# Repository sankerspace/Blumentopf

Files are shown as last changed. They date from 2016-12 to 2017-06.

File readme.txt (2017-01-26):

Hier ist ein Spannungsmess-Testprogramm (VoltageCheck) sowie der ganze restliche 
Code (noch in Entwicklung) vom Messknoten (SensorNode) und einem 
Beispiel-Controller (RF_Receiver).
###### Einrichtung Arduino IDE #########
Im Ordner libraries sind sämtliche Bibliotheken die wir dür das Projekt 
benötigen In der Arduino IDE muss der Standard Ordner für die installierten 
Libraries geändert werden auf die Location von der Blumentopf Repository, damit 
sind automatisch sämtlichen notwendigen Libraries für unser Projekt aufgenommen.

###### Sensor Node ######

X	Sensoren auslesen (Implementiert und getestet. Geht sehr gut)
X	Protokoll
		implementiert und getestet:
			Beim Startup beim Controller registrieren 
			ID beziehen, falls noch keine vorhanden
			Daten übertragen
			Schlafdauer empfangen und schlafen gehen
			Speichern der Daten im EEPROM bei RF Ausfall und auslesen der Daten, 
			wenn vom Server angefordert
X	RTC synchronisieren
-	Interrupt Alarm von RTC

** Known problems: **

	If RTC is unplugged, sketch will hang due to a bug in the I2C library.

###### Controller  ######

Ist ein simpler Controller, der zeigt wie man die Funktionen von dem Protokoll 
verwendet.
Features:
	ID-verwaltung:
		-) Hat der Node noch keine ID wird eine vom Controller vergeben.
		-) Der Controller führt eine Liste mit den ihm bekannten Nodes.
	Kommunikationsprotokoll:
		-) Der Controller antwortet auf Registrations und Messdaten-Nachrichten.
		   Dabei schickt er Instruktionen mit.

Fehlt:
	Die Möglichkeit über ein Front-End die Messintervalle eizustellen und 
	Messknoten mit Pumpknoten zu verknüpfen.	Ein Algorithmus wann welche Pumpen 
	aktiviert werden und ggf. ein Frontend für die Parameter des Algorithmus

###### Raspberry Pi  ######

    fehlt noch!!!

	Data Logging:
		-) Alle Nachrichten werden passiv geloggt.
		   Den Teil kann man dann auf dem Pie übernehmen und ein Datenbankinterface 
		   basteln

###### PumpNode ######

Hardware fertig

Software:
    Pumpe ansteuerbar
    RF Kommunikation

fehlt noch:
    Interrupt/Sleep vom Pump-Node
    Protokoll Implementierung

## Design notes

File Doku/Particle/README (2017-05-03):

Controller should work on a Particle Photon, but also can run an Arduino
Here you can find a description how to prepare/compile to run the Controller.ino
on a Particle Photon

Configuration on the breadboard:
-Particle Photon
-DS3231 Real Time Controller
-nRF24L01+ 

Pin Configuration:
  rf-Gnd/Pin1 to ground-breadboard
  rf-Vcc/Pin2 to  3,3v-breadboard
  rf-CE/Pin3 to   D6-photon
  rf-CS/Pin4 to   A2-photon
  rf-SCK/Pin5 to  A3-photon
  rf-MOSI/Pin6 to A5-photon
  rf-MISO/Pin7 to A4-photon

  DS3231/VCC  to   3,3v-breadboard
  DS3231/Gnd  to   Ground-breadboard
  DS3231/SCL  to   D0-photon  
  DS3231/SDA  to   D1-photon

1)  Prepare Atom IDE (half online/ half offline)

  https://atom.io/packages/particle-dev
 
2) Create Symbolic Links to all cpp and h files necessary for controller.ino
    
    Start bash script <path-to_repo>/Doku/Particle/createSymbols.sh
    which automatically creates alls symbol links to these files 
    inside folder  <path-to_repo>/Controller 
 
3)  Include R24 Lib and use firmware version 0.6.0 particle dev 

  Our Library Rf24 in folder libraries has no compability for Spark processors,
  in order we have to introduce the "particle-rf24" library from 
  particle public libraries  
  -> include in project-properties : dependencies.particle-rf24=0.0.2
      in a new line
      
  some compile errors occured in photon firmware version 0.6.1,
  so i cannot choose the most actual firmware version and have to
  compile for version 0.6.0
   
4) Use particle-cli (for use on command line and with better error output)

    sudo npm install -g particle-cli
   
  but you have to install nodejs before!

  Tips Atom IDE:
  
    packets you should install: 
    (https://benmccormick.org/2016/01/11/the-most-interesting-atom-packages-ive-found-so-far/)
    git-time-machine
    language-particle
    todo-show  
    git-plus
    autocomplete
    autocomplete-clang
    autocomplete-paths
    minimap

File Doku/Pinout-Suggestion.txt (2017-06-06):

Das Pinout ist ein Kompromiss zwischen dem was der Ezio auf seinen Platinen hat und dem was
wir in dem Programm verwenden. Außerdem können dann die DS_1302 und DS_3231/3232 RTCs leicht
ausgetauscht werden.
RF24 := CE, CS, MOSI, MISO, SCK, IRQ
 Arduino_Pin/Particle_Pin
 12/A4 13/A3   9/D6 
----------------------------
|MISO | SCK  |  CE  | GND |
----------------------------
|IRQ  |MOSI  |  CS  | VCC |
----------------------------
       11/A5  10/A2   
    RF CHIP           |
   ___________________|
     __    __    __   |                   
    |  |  |  |  |  |  |
    |  |  |  |  |  |  |
    |  |  |  |  |  |  |
____|  |__|  |__|  |__|

RTC  := SDA, SCL
/*
**** pinout                                                                                                
***                0    |    1    |    2    |    3    |    4    |    5    |    6    |    7    |    8    |   9     |   10   |   11   |   12   |   13   |
=====================================================================================================================================================
* Controller  | --------| --------|         |         |  Button |         |         |         |  if ARDUINO same sas pump,sensornode, otherwise PARTICLE
* SensorNode  | --------| --------|         |         |         |  DHT11  |SENS_PWR |         |         |   CE    |   CS   |  MOSI  |  MISO  |   SCK  |   
* PumpNode    | --------| --------| Pump1   |  Pump2  |  Button |         |         |         |         |   CE    |   CS   |  MOSI  |  MISO  |   SCK  |   
* Particle	  |   SDA   |   SCL   |         |         | RTC_PWR |         |   CE    |         |------------------------------------------------------

*             |    A0   |    A1   |    A2   |    A3   |    A4   |    A5   |    A6   |    A7   | 
=====================================================================================================================
* Controller  |         |         |         |         |         |         |  -----  |  -----  |
* SensorNode  | Battery |  Light  |Moisture1|Moisture2|   SDA   |   SCL   |  -----  |  -----  |
* PumpNode    |         |         |         |         |   SDA   |   SCL   |  -----  |  -----  |
* Particle	  |         |         |   CS    |   SCK   |  MISO   |  MOSI   |  -----  
*/

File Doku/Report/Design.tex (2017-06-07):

For the topology of the network multiple options have been considered. Eventually we decided to split up the sensing and pumping functionality into separate nodes, the sensor node and the pump node.
There can be up to $%2^{16}$ nodes of both types to offer flexibility with the size of the system. A controller node coordinates the communication of the nodes and the front-end.
The front-end should offer access to the main functions of the system. In particular it has to display the sensor values and offer the possibility to activate individual pumps.
Additionally a dater logger was requested to record all communication  and store it into a database.\\
To reset the nodes a button has been implemented to reset the devices. It has to be pressed during restart. Instead of a button it also is sufficient to pull the digital pin 4 high some seconds during restart.

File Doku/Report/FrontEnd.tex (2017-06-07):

In order to adjust, maintain and control the system, it is necessary to have direct access to certain features. As it is not feasible to interact with the Photon or an Arduino a front-end has been developed. Note that the functions offered by the front-end are also accessible through console.particle.io or the Particle app. However the front-end is more user friendly. The front end offers the possibility to mate a sensor node with a pump node, to see the sensor data of a particular node and to manually start the watering of a flower pot.
This chapter can be considered as a user guide for operating the whole system.
In the following the features are introduced with an example each.

\subsubsection{Mapping}
For watering the flowers the system needs to know which sensors monitor which flowers. This is called the mapping and can be done via the front end.
Each pump node can support up to two pumps and every sensor node can own up to two moisture sensors. \textbf{A word of warning}: It is important to make sure to chose the right pump and the right sensor, otherwise the flower might not be watered, but the floor instead.\\
A pump does not need to be mapped and a moisture sensor does not need to be mapped to.
To map a pump node to a sensor node they have to be selected in the drop down list. Further the user has to chose which moisture sensor should be and which pump should be mapped. An example is shown in the following figure.

\begin{figure}[h!]
	\begin{center}
	
	\caption{How to map a pump to a moisture sensor.}
	\label{fig:mapping}
	\end{center}
\end{figure}

\subsubsection{Sensor View}
To monitor the most recent environment values, all sensor data can be listed in the front end.

\begin{figure}[h!]
	\begin{center}
	
	\caption{Overview of the sensor data.}
	\label{fig:sensor_overview}
	\end{center}
\end{figure}

\subsubsection{Manual Watering}
Under special circumstances one might decide to manually add some water to a flower. In this case the front end offers a comfortable way to do so.
The user only has to chose the flower from the drop down menu and how long the water should be running. (in seconds)
The following figure shows an example.

\begin{figure}[h!]
	\begin{center}
	
	\caption{How to manually water a flower.}
	\label{fig:manual_watering}
	\end{center}
\end{figure}

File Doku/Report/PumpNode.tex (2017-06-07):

The purpose of the pump node is to serve as an actuator and activate a pump for a specified time on request of the controller. An early draft involved a 3d printed reservoir where the electronics would be incorporated. However it turned out to be inflexible and therefore only the pump mountings have been printed and the mountings are attached to a bucket. From that bucket a hose leads to the pump and further to the flower.
It was required that the pump node supports two pumps which can be activated individually. Since the ATmega itself cannot provide sufficient current to power the pumps, a relay is used for each pump. % which relay shield do we use here?
A specific protocol takes care of the reliable communication between the pump node and the controller. It has been carefully designed to avoid freezing of the node and to ensure reliable operation of the pumps.\\

\subsubsection{Actuator}
As the task of the pump node is to water flowers, it is equipped with two pumps. Alternatively solenoid valves have been considered, however pumps are easier to use and a reliable solution. The chosen peristaltic pumps require high currents around 200mA and a voltage of 12V. Therefore they cannot be powered by Arduino pins, but have to be powered from an own power source like a voltage booster or an additional power supply. We chose an external 12V power supply to power the node.
The Arduino switches two relays which in turn power the pumps. As high current is needed, the pumps are not activated concurrently, but sequentially. They typically will be active for around 30 seconds.
Figure \ref{fig:pumpnode} illustrates a pumpnode with one pump.

\begin{figure}[H]
	\begin{center}
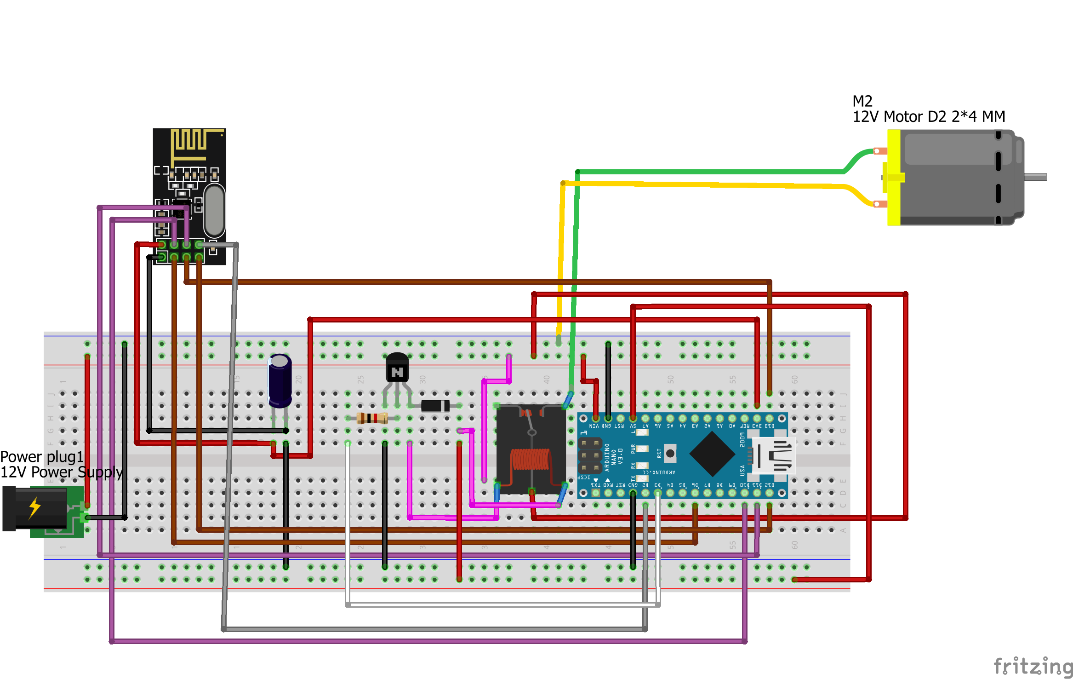
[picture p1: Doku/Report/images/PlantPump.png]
	
	\caption{Breadboard schematic of the pump node.}
	\label{fig:pumpnode}
	\end{center}
\end{figure}

\subsubsection{Fall-back Mode}
To guarantee a dependable solution resistant to external factors such as a failing internet connection or wireless jamming attacks, a fall-back mode has been implemented to water the flowers reliably, even if the control node is unavailable.

For this purpose the pump node uses all incoming messages, also those addressed to other nodes, to detect the availability of the controller. If the pump node does not receive any messages from the controller for a specified timeout\_duration, it assumes the controller is offline and goes into a fall-back mode.

The parameters for the fall-back mode are:
\begin{itemize}
\item timeout\_duration
\item enable
\item time
\item watering\_duration
\end{itemize}

These parameters can be set at the IOT front-end-interface and get transmitted to the pump nodes by the controller at the pump node registration and with every pump request. (so in case they get changed the pump node stays up to date)
In case the fall-back is disabled, no action takes place if the controller is unavailable.
In case the fall-back is enabled and the controller is unavailable, daily at the specified time the pump node pumps for the specified watering\_duration.

This mechanism does not guarantee a perfect watering, however it prevents the plants from drying.

To make the fall-back visible to the monitor node, a notification message is broadcasted via the wireless network containing the timestamp, pump duration and last timestamp from a controller message.

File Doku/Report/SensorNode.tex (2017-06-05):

%about the sensor node...

The sensor node provides data about the current state of the flower environment to the controller.
It has been developed as a low power device which guarantees long battery duration.
Arduino has been chosen as platform for this node because of its powerful libraries and support. Also the microcontroller has to offer sufficient ADCs and GPIO pins to access all required modules such as communication chip, real time clock and sensors. Other platforms such as XBee could not be used, as they do not directly support protocols such as TWI. Also they are expensive.
In particular we chose the Arduino Mini 3.3V 8MHz board, as it is the most basic board and therefore offering the lowest power consumption. Further details about minimizing the power consumption are explained in \ref{sec:lowpower}.

The sensors used are:
\begin{itemize}

\item \textbf{DHT11 - Temperature and humidity sensor}\\
The datasheet claims this sensor reaches a repeatability of $\pm0.2°C$ for the temperature and an accuracy of $\pm 5\%$ for humidity. It seems to be a widely used sensor for arduino projects, however in operation its humidity accuracy was far worse than promised by the manufacturer and a cumbersome calibration of the sensor is needed. Further research showed that it is not always a reliable humidity sensor and probably should be replaced by the more expensive DHT22 or other alternatives. We kept the sensor in the setup, however no decision has been based on its data.

\item \textbf{Moisture sensor}\\
We tried two types of moisture sensors. A resistance based sensor and a capacitive sensor. The electrodes used for the resistance sensors interact with the water in the soil as current flows. This pollutes the soil and destroys the sensor over time. Performing only sporadic measurements postpones this effect, however it cannot be avoided. Capacitive sensors do not interact with the soil as they measure the humidity through the capacity of the soil, not its resistance. So no current flows through the soil and there are no metallic or corrosive electrodes.\\

The resistance based sensor consists of two parts, the resistance probe (YL-69) and a control board (YL-38). The probe will be put into the measured soil, while the board should stay dry. It provides an analog signal. The ATmega328 has a 10 bit ADC, so the result read from the ADC is an integer between 0 and 1023.\\

The test showed that in a dry state the sensor shows 1023. Connecting the electrodes with a finger leads to a value around 1000.\\
Also in dry soil the readout is 1023, but as we pour water into the pot, it continuously decreases down to a few hundred.\\

We might have to calibrate the moisture levels for different flower or soil types, but in general the sensor seems to do the job very well.\\

The capacitive sensor used is the SEN0193. It is handled the same way as the YL-69 sensor on the software side, however it does not influence the soil.

\item \textbf{Brightness sensor}\\
To gather information about the brightness in the environment, a photoresistor has been used. This is a semiconductor that reacts to light. The manual of the sensor suggested the range of the photoresistor is between 500$\Omega$ (bright) and 50$k\Omega$ (dark). 
Further it suggested to use a 1$k\Omega$ resistor for the voltage divider. An arduino tutorial \citep{misc:photoresistor_tutorial} suggested 10 $k\Omega$. So we decided to measure the actual resistor values and use the formula from the lecture to calculate the matching resistor of the voltage divider. % , 26$k\Omega$ was a good choice  

The measurements showed that the actual photoresistor range is 500$\Omega$ to 1.7$M\Omega$.\\
\begin{equation}
R_1 = \sqrt{R_{max}*R_{max}} = \sqrt{500*1700000} = \sqrt{850000000} = 29k\Omega
\end{equation}

The closest resistor available to us was 26$k\Omega$.\\
These values differ to those suggested by the tutorials, but since also the photoresistor has different values, our choice seems feasible. Also we are convinced a higher resistor will not harm the components and result in lower power consumption in contrast to a small resistor.\\
So we connected the chosen pulldown resistor between ground and an ADC pin of the Arduino. To complete the voltage divider the photoresistor was connected between VCC and the ADC pin.\\

The sensor worked very well in the tests and showed a value between 30 (covered sensor) and 950 (next to a light bulb). That confirmed our choice of the resistor.\\

\item \textbf{Battery Voltage Sensor}\\
As the sensor node is powered by a battery it is good to have information about the battery status.
This can be done by measuring the voltage of the battery via a voltage divider. There are two ways of setting the voltage reference of the ADC unit. Either the VCC of the ATmega or the internal reference voltage of 1.1V can be used.
The former has the advantage of higher accuracy, assuming a stable supply voltage. However a supply voltage lower than 3.3V cannot be measured correctly. Notice that the ATmega328 will continue to operate even at a supply voltage as low as 2.7V, although some external components might fail.
 The second version has the advantage that also supply voltages below 3.3V can be measured, however it has to be calibrated for each ATmega individually to be as precise.

In any case a voltage divider is needed to convert the voltage from 0-6V to 0-3.3V respectively 0-1.1V. The design of the voltage divider is a trade\-off between measurement precision and power consumption. \cite{misc:battery_voltage_measurement} If its total resistance is low, the power consumption of the voltage divider is too high for a low power device. If the resistance is too high, the measurement will become unstable and a capacitor becomes necessary to smooth the measurements. We decided to use a resistance of $100k\Omega$ between GND and the ADC pin as well as $500k\Omega$ between VCC and the ADC pin. This seemed to be a good trade-off without requiring a capacitor.

% Ezio: 
% VCC - 1MO - ADC - 39kO - (1MO / 470kO) - 22kO - GND (1MO / 381kO)

% Ours:
% VCC - 500kO - ADC - 108kO - GND 			(500kO / 100kO)

\end{itemize}

\subsubsection{Low Power Capability}
\label{sec:lowpower}

As mentioned before, the Arduino Mini 3.3V 8MHz is the basis of our sensor node platform. However the Arduino uses about 6 mA in standby. With this current consumption a set of batteries (assuming a capacity of 2000mAh) would be empty within 14 days. In a network consisting of 7 sensor nodes, every second day batteries would be needed to be changed. This motivates to look into further power saving techniques for the Arduino.\\

\subsubsection{Power supply}

One of the obvious questions is the supply of the operating voltage. It has been looked into the following options:

\begin{itemize}
\item \textbf{Using the Arduino voltage regulator}
The Arduino board can be powered directly from the battery and generate its own supply voltage.
However this regulator is very inefficient.

\item \textbf{Using an external voltage regulator}
A more efficient external regulator can be used instead of the onboard regulator. The original regulator will still consume a small current, even if not used. Therefore it should be removed in this case. The external regulator will require a supply voltage of typically 100-200mV above the output voltage. The regulator tested by us, MCP1700-3302E, needs 3.5V, so in case of three batteries this is 1.17V per battery.\\
During the discharge process of a battery its output voltage drops. Once the voltage drops under the required supply voltage of a voltage regulator, the output voltage of the regulator will not match 3.3V anymore.\\
Figure \ref{fig:dischage_curve} illustrates the battery voltage of a AA NiMH battery over different loads. %It is important to notice that with a low load the battery voltage stays above 1.17V for a longer period.
It is important to notice that with a low load the ampere hours obtained from the battery increases. So decreasing the current used by the system by half results in more than just doubled battery life.
In our application the load is less than 1mA with some 15mA pulses during data transmission. This is even far less than the uppermost line indicates. It can be concluded that the energy remaining in the battery once its voltage drops below 1.17V is less than 400mA.

\item \textbf{Using a buck-boost converter}
A conventional voltage regulator needs a supply voltage of at least little over 3.3V to provide a 3.3V output.
A buck-boost converter like the Pololu reg 12a which we tested, can convert voltages above 0.5V to constant 3.3V.\\
This is beneficial because of the dropping battery voltage during the discharge process. 
A buck-boost converter has a lower required supply voltage (0.5V) and therefore gets nearly all energy out of the battery. However it turned out that for very low currents, like in our sensor node, the power consumed by the Pololu is much higher than for the linear voltage regulator. This diminishes the advantage of the Pololu and even turns it into the worse choice in terms of energy efficiency. Regarding costs the linear power regulator beats the pololu by an order of magnitude.

\end{itemize}

\begin{figure}[htbp]
\begin{center}
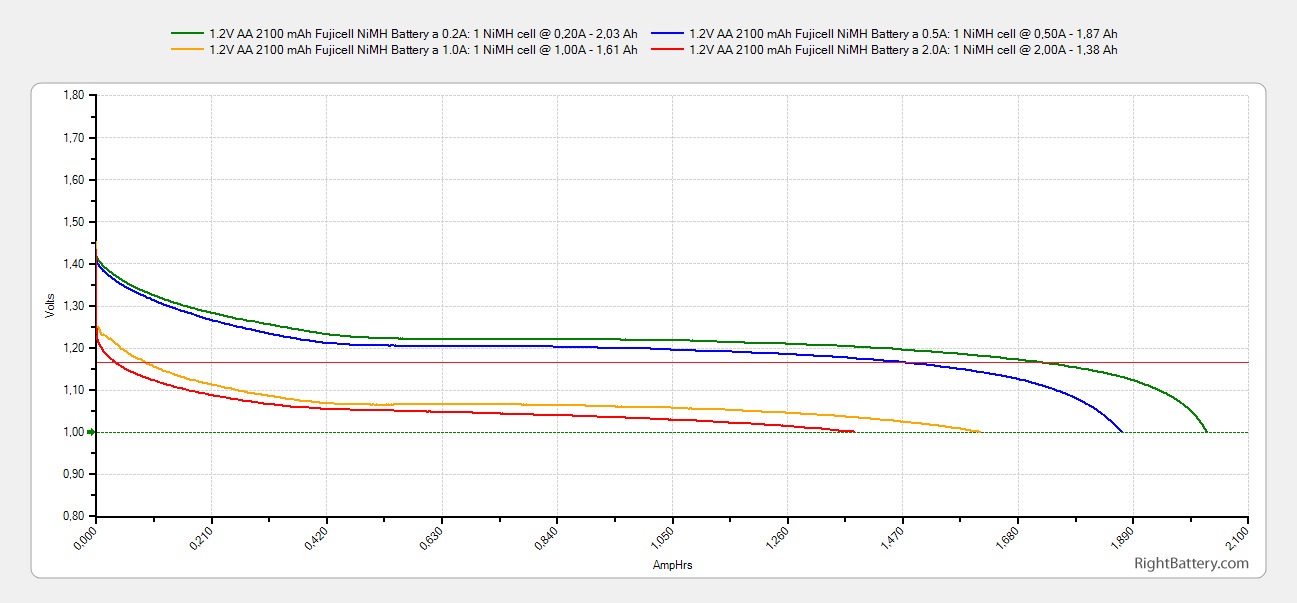
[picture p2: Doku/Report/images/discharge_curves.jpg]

\end{center}
\caption{Discharge curves over different currents}
\label{fig:dischage_curve}
\end{figure}

We tried all solutions in our tests, however for the final solution we recommend the linear voltage regulator with adequate batteries (3 x 1.5V or 4 x 1.2V).

\subsubsection{Power consumption optimizations}
To make the batteries last as long as possible, the node should use as little power as possible.\\
The biggest power safer is to put the microcontroller and all peripheral devices including all sensors into sleep mode as much as possible.\\
This reduces the power of the system to around 1.5mA and gives 8 weeks of battery life per node. This is a big improvement, however far away from a convenient solution and the technical limits.\\
One further optimization is to remove the power LED used to indicate the Arduino is running, as there is no need for it and the LED uses a lot of power. The LED can be removed by adding tin to connect both legs, heating them up uniformly and pulling away the LED with tweezers. This decreases the consumption to about 0.26 mA (45 weeks). \\
Disabling TWI before sleep saved another 170µA.\\
Removing the parasiting onboard voltage regulator saved further 75µA. However de-soldering of medium sized SMD components requires special equipment, skills or patience.\\
The resulting consumption for the design including all final components and using the external voltage regulator is 15µA. (4.5V ==> 67.5µW)
Using the Pololu the same design needs 90µA (4.5V ==> 405µW).
It can be concluded that in this situation an appropriate voltage regulator is more efficient than a Pololu. Also the voltage divider is a far cheaper solution.\\

\paragraph{Battery}
One crucial factor obviously is the kind of battery itself. The following summarizes the key issues of batteries in our application.
\begin{itemize}
\item \textbf{Voltage}\\
It must be mentioned that every battery type operates at a different voltage, what has to be considered at the choice of battery.
Three 1.5V alkaline batteries have been assumed in the calculations above, resulting in 4.5V total. Using rechargeable batteries with 1.2V each, like nickel metal hydride batteries, the resulting total 3.6V are just slightly above the threshold for the voltage regulator to operate, so they will fail very soon. In this case the Pololu would have the better performance. For operation with the voltage regulator 3x1.5V LSD NiMH batteries or 4x1.2V rechargeable alkaline batteries are recommended.

\item \textbf{Capacity}\\
Obviously batteries with higher capacity last longer without replacing them.

\item \textbf{Temperature range}\\
Not all batteries withstand extreme temperatures. For example conventional NiMH batteries are not supposed to be used in cold environments, while their self-discharge rate drastically increases at high temperatures. LSD NiMH however can resist cold temperatures.

\item \textbf{Self discharge rate}\\
Conventional NiMH batteries have a high self discharge rate. Even if not used, they loose half their energy after one month. Low self discharge NiMH (LSD NiMH) batteries loose only a fraction of this energy per month $(<3\%)$ and can be used for several years without recharging.
\end{itemize}

\subsubsection{PCB}
In order to incorporate all components into a small box, a PCB has been designed by our supervisor using the Fritzing tool. The yellow traces are on the top side and the orange traces on the bottom. To offer flexibility with the power supply of the sensors, it can be selected whether they should be powered by the normal VCC pin or powered by an arduino pin to be able to deactivate all sensors during low power phases.
The board has been produced by the Fritzing company tested with our software. It works as expected.
\begin{figure}[h!]
	\begin{center}
%	\includegraphics[scale=2]{images/PlantSensorPCB.pdf}
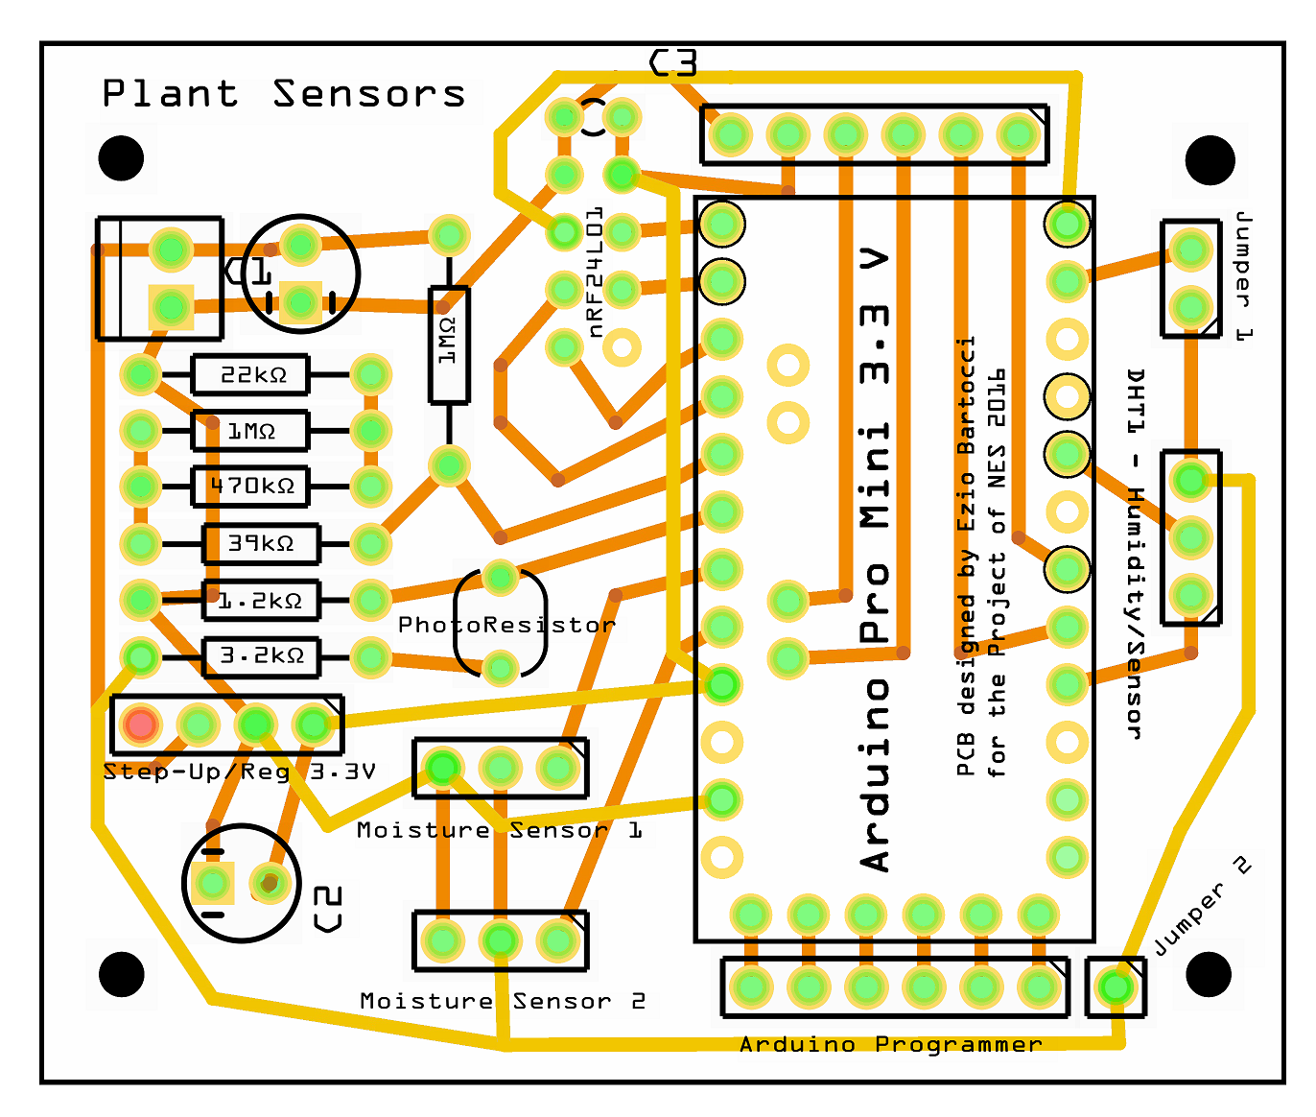
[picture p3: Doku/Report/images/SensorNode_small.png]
	
	
	\caption{PCB design of the sensor node.}
	\label{Setup_overview}
	\end{center}
\end{figure}

\subsubsection{Data storage}
As the communication between a sensor node and the controller might be faulty, the data shouldn't get lost. If the sensor node sends data to the controller and doesn't get a response, the data is stored in the EEPROM of the sensor node until the controller requests the data.
The size of the EEPROM is limited to 1KB, therefore only around 25 data sets fit into the storage.
Another issue with using EEPROM as storage is that the write cycles it endures are limited. Therefore an algorithm has been developed to ensure equal wearout of the EEPROM cells. In case the controller does not request the data and the EEPROM memory is full, the oldest data in the storage is replaced with the most recent data. 

\subsubsection{State diagram}

\begin{figure}[H]
	\begin{center}
	
	\caption{State diagram of the sensor node.}
	\label{Setup_overview}
	\end{center}
\end{figure}

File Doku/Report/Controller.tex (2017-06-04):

The controller keeps track of all nodes and handles their registration. It coordinates the communication of the sensor and pump nodes and maintains a schedule of which node is allowed to transmit at which time.
The controller also executes the watering policy that the user has selected for each flower.
For this task it wirelessly communicates with the sensor nodes situated in the flower pots and the pump nodes situated next to the water tanks. The sensor nodes provide the controller with the most recent measurement values, whereas the pump nodes executes the pump commands received from the controller.
The controller also provides an interface for the front end to get the newest data and to perform certain actions.
It was a restriction to use the Particle Photon as controller hardware.

\subsubsection{State diagram}

\begin{figure}[h!]
	\begin{center}
	
	\caption{State diagram of the controller.}
	\label{Setup_overview}
	\end{center}
\end{figure}

States:
\begin{itemize}
	\item Check pending tasks

		This is the begin of the loop() Function. The controller will always come back to this state to check which tasks are pending. The following actions are possible:

		\begin{itemize}
			\item A NRF24 message is arrived, process this message.
			\item Also if an interactive command has arrived via the IOT framework, this command has to be processed. (Typically sending an instruction to a Motor Node)
			\item If, according to the watering schedule, a pump node should take an action now, the controller goes to the ``Send Watering Command to Motor Node'' state
			\item If a Motor Node did not respond as expected, an error handling sequence should be started (writing to log and if needed respond to the IOT framework)
		\end{itemize}

	\item Send Watering Command to Motor Node
		Whenever the controller decides a pump node should start to pump, this function is called. 			It prepares and sends a message to concerned the pump node. It also writes the message content to a log file.
	\item Write Pump Node Timeout to Log
		If a pump node does not reply within the specified timeout duration, an entry into the log file has to be written. In case the command of the concerned message has been triggered by the IOT framework, the controller will move to the ``Send Error Notification to App'' state. Otherwise it enters the ``Reschedule Watering'' state.
	\item Send Error Notification to App
			If a IOT command could not be successfully executed, the IOT framework has to be notified about the problem. Afterwards the controller goes back to checking for pending tasks.
	\item Reschedule Watering
		If a scheduled watering task failed, the controller needs to reschedule this watering task.
		There are many possible algorithms for this such as:
		\begin{itemize}
			\item Skip this watering task and proceed as usual
			\item Retry the watering task a certain number of times. If it fails, proceed as usual
			\item Reschedule the watering of this pump node in a given fashion.
		\end{itemize}
		For a first version it is sufficient to skip the watering, if it failed.
		
	\item Write Motor Node Response to Log File
		If a motor node responds to a control command, this response has to be logged to a log file. Afterwards the controller processes the response.
	\item Mark Command as Read
		The watering command is marked in the controller internal command list as ``read by the node''. Otherwise a timeout would occur.
		
	\item Process State Message
		As the pump node finished to pump, it will send a state message to the controller indicating the end of the pump sequence. This message can be responded to by the controller, but it doesn't have to be.
		
	\item Process Sensor Data
		When the controller receives data from a sensor node, it stores the data. Later this data will be used for the watering algorithm and statistical analysis. Afterwards it will check whether the sensor node has data stored in its EEPROM. This will be the case if the controller was unavailable to the sensor node for some time. If there is EEPROM data the controller can choose whether it wants the data to be transmitted now, later or not at all. If the latter is the case, the node will delete its sensor data. If the controller has currently time to receive the EEPROM data, it should request it. Otherwise the data might get lost. If there is a lot of traffic scheduled in the next slots, the controller can postpone the EEPROM data transmission. In this case the next sensor node transmission should be scheduled in a slot that is followed by empty slots. This way it is guaranteed that there is enough time to transmit all EEPROM data.
	
	\item Respond
		In the respond state a response is prepared and sent to the node from which the last message has been received. Its content is based on the previous states.

\end{itemize}

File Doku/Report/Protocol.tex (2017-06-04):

The application itself and project requirements bring certain constraints regarding the system architecture and protocol. For communication XBee, WiFi and RF24L01 chips have been considered. Because of costs, power and sensor constraints XBee and WiFi turned out to be not feasible.

\paragraph{Sensor Node <--> Controller}
One main constraint is that the sensor nodes should not be connected by cables. Therefore the communication with the controller has to be wireless and the node cannot be powered by the power grid.
For receiving messages on a wireless interface, the wireless module has to be actively listening continuously. The chosen modules RF24L01+ use about 15mA in listening mode. That makes a controller initiated communication impossible, as the constantly activated listening mode of the RF module would drain the batteries within 5 days.
To solve this problem, we chose that the sensor node initiates the transmission, waits for the answer of the controller and puts the RF module to a low power mode. This is an elegant solution for keeping the power down, however it is much more difficult to implement. It makes it necessary that every sensor is assigned a precise time at which it is expected to send its next measurement data to the controller in advance. Therefore the controller has the task of coordinating these timeslots and synchronizing the clocks of the sensor nodes. New sensor nodes should automatically be integrated into this schedule.

For registering nodes and perform data exchanges a protocol has been developed. The developed library provides access to the protocol registers to use the functionality of the protocol.

Status register in the node --> controller message:

\begin{table}[htbp]
        \small
        \setlength\tabcolsep{2pt}
\begin{tabular}{ |l|c|c|c|c|c|c|r| }
%  Test ID & measurement base frequency [MHz] & measurement scale factor & PLL factors (m/d) & measurement frequency [MHz] & PISO base frequency [MHz] & PISO scale factor & PISO frequency [MHz]\\ \hline
\hline
  Bit & name & description & 0 - meaning & 1 - meaning\\ \hline
  0 & RTC\_RUNNING\_BIT & RTC is paired on the node & no RTC & RTC paired \\ \hline
  1 & MSG\_TYPE\_BIT & type of message & registration request & data \\ \hline
  2 & NEW\_NODE\_BIT & new or known node & known node & new node \\ \hline
  3 & EEPROM\_DATA\_AVAILABLE & is data in the EEPROM & no data & data available\\ \hline
  4 & EEPROM\_DATA\_PACKED & kind of data & live data & EEPROM data\\ \hline
  5 & EEPROM\_DATA\_LAST & more EEPROM data pending & more data & not more data \\ \hline
  6 & NODE\_TYPE & type of node & sensor node & pump node\\ \hline
\end{tabular}\\
\end{table}

Status register in the controller --> node message:

\begin{table}[htbp]
        \small
        \setlength\tabcolsep{2pt}
\begin{tabular}{ |l|c|c|c|c|c|c|r| }
%  Test ID & measurement base frequency [MHz] & measurement scale factor & PLL factors (m/d) & measurement frequency [MHz] & PISO base frequency [MHz] & PISO scale factor & PISO frequency [MHz]\\ \hline
\hline
  Bit & name & description & 0 - meaning & 1 - meaning\\ \hline
  0 & REGISTER\_ACK\_BIT & registration acknowledge & no reg & registration\\ \hline
  1 & FETCH\_EEPROM\_DATA1 & &  &  \\ \hline
  2 & FETCH\_EEPROM\_DATA2 &  & &  \\ \hline
  3 & ID\_INEXISTENT & id invalid & id valid & id invalid\\ \hline
  7 & ID\_REGISTRATION\_ERROR &  & &  \\ \hline
\end{tabular}\\
\end{table}

Further the combination ``00'' in the FETCH\_EEPROM\_DATA1/2 bits indicates the EEPROM data shouldn't be transmitted now, ``01'' means the sensor node should send the data now and ``10'' means the node should delete the stored EEPROM data.

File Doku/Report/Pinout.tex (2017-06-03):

To quickly change the role of an ardunino, it is a good idea to have a standardized pinout for all sketches. The following tables summarize the pinout.\\

Digital Pins:

\begin{table}[htbp]
        \small
        \setlength\tabcolsep{2pt}
\begin{tabular}{ |l|*{7}{c|}r| }
%  Test ID & measurement base frequency [MHz] & measurement scale factor & PLL factors (m/d) & measurement frequency [MHz] & PISO base frequency [MHz] & PISO scale factor & PISO frequency [MHz]\\ \hline
  \hline   & 2 & 3 & 4 & 5 & 6 & 7 & 8 & 9-13 \\ \hline
  Controller & DS\_1302 & DS\_1302 & DS\_1302 &  &  & Button  & RTC\_PWR &  RF24   \\ \hline
  SensorNode & DS\_1302 & DS\_1302 & DS\_1302 &  DHT11  &         & Button  &SENS\_PWR &  RF24  \\ \hline
%  PumpNode & DS\_1302 & DS\_1302 & DS\_1302 &  Pump1  &  Pump2  & Button  &         &  RF24   \\ \hline
  PumpNode & & & &  Pump1  &  Pump2  & Button  &         &  RF24   \\ \hline
  Particle & ?? & & & & & & &  \\ \hline
\end{tabular}\\
\end{table}

Analog Pins:

\begin{table}[htbp]
        \small
        \setlength\tabcolsep{2pt}
\begin{tabular} { |l|*{7}{c|}r| }
%  Test ID & measurement base frequency [MHz] & measurement scale factor & PLL factors (m/d) & measurement frequency [MHz] & PISO base frequency [MHz] & PISO scale factor & PISO frequency [MHz]\\ \hline
  \hline   & A0 & A1 & A2 & A3 & A4 & A5 & A6 & A7 \\ \hline
  Controller & & & & & DS\_3231 & DS\_3231 & &  \\ \hline
  SensorNode & Battery & Light & Moisture1 & Moisture2 & DS\_3231 & DS\_3231 &  &  \\ \hline
%  PumpNode &  & & & & DS\_3231 & DS\_3231 & &  \\ \hline
  PumpNode &  & & & & & & &  \\ \hline
  Particle & & & & & & & &  \\ \hline
\end{tabular}\\
\end{table}

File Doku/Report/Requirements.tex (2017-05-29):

The system should substitute the need for human interaction. Therefore it has to sense as much information relevant to the task of watering as possible and it needs the possibility of adding water to the flower pots. Furthermore it should be reliable, so it doesn't have to be supervised.

\begin{itemize}
\item \textbf{All data containing information vital for the watering task has to be tracked.}
This contains ambient temperature, ambient humidity, soil moisture and brightness.
The data has to be logged in a database.

\item \textbf{Reliable flower watering through pumps or valves.}
Based on the sensor data the system has to make decision when to water the plants and for how long.
It is critical that this part is fail safe. If there are a failures of any components of the system, the water supply has to be automatically cut off to avoid damage.

\item \textbf{Any influence to the flower or surrounding through the system has to be avoided.}
This in particular concerns the choice of sensors, pipes, pumps and water tanks to not pollute the soil, keep the noise level low, being an efficient solution and not disturbing other electronic devices nearby.

\item \textbf{The hardware solution should be visually appealing.}
Since the system should be usable in living areas, it has to be as unobtrusive as possible.
As a result the data communication should be wireless and the sensor nodes run on battery.

\item \textbf{Battery powered low power sensor nodes.}
The sensor nodes should be powered by batteries, not the power grid. However the batteries also should last long time to decrease the maintenance work, what means the power supply is not trivial and needs to be paid attention to while developing the sensor node.

\end{itemize}

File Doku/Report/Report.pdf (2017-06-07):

# Network Embedded Systems [VU] Semster Project - Protocol

### Vienna University of Technology June 7, 2017

### Helmut Bergmann, Matr.Nr. 0325535

0325535@student.tuwien.ac.at

### Bernhard Fritz, Matr.Nr. 0828317

0828317@student.tuwien.ac.at

### Marko Stanisic, Matr.Nr. 0325230

0325230@student.tuwien.ac.at

Everyday life brings many repetitive tasks. As technology increases also more complicated tasks can be automatised, relieving humans from repetitive tasks. In our project we want to develop a system that handles the watering of plants in order to decrease the number of routine tasks done in a household and also to reliably continue watering even if no person is at home for a longer period of time.

## 1 Requirements

The system should substitute the need for human interaction. Therefore it has to sense as much information relevant to the task of watering as possible and it needs the possibility of adding water to the flower pots. Furthermore it should be reliable, so it doesn’t have to be supervised.

- All data containing information vital for the watering task has to be tracked. This contains ambient temperature, ambient humidity, soil moisture and brightness. The data has to be logged in a database.
- Reliable flower watering through pumps or valves. Based on the sensor data the system has to make decision when to water the plants and for how long. It is critical that this part is fail safe. If there are a failures of any components of the system, the water supply has to be automatically cut off to avoid damage.
- Any influence to the flower or surrounding through the system has to be avoided. This in particular concerns the choice of sensors, pipes, pumps and water tanks to not pollute the soil, keep the noise level low, being an efficient solution and not disturbing other electronic devices nearby.
- The hardware solution should be visually appealing. Since the system should be usable in living areas, it has to be as unobtrusive as possible. As a result the data communication should be wireless and the sensor nodes run on battery.
- Battery powered low power sensor nodes. The sensor nodes should be powered by batteries, not the power grid. However the batteries also should last long time to decrease the maintenance work, what means the power supply is not trivial and needs to be paid attention to while developing the sensor node.

1

## 2 Design

### 2.1 Sensor Node

The sensor node provides data about the current state of the flower environment to the controller. It has been developed as a low power device which guarantees long battery duration. Arduino has been chosen as platform for this node because of its powerful libraries and support. Also the microcontroller has to offer sufficient ADCs and GPIO pins to access all required modules such as communication chip, real time clock and sensors. Other platforms such as XBee could not be used, as they do not directly support protocols such as TWI. Also they are expensive. In particular we chose the Arduino Mini 3.3V 8MHz board, as it is the most basic board and therefore offering the lowest power consumption. Further details about minimizing the power consumption are explained in 2.1.1.

The sensors used are:

- DHT11 - Temperature and humidity sensor
The datasheet claims this sensor reaches a repeatability of ±0.2C for the temperature and an accuracy of ±5% for humidity. It seems to be a widely used sensor for arduino projects, however in operation its humidity accuracy was far worse than promised by the manufacturer and a cumbersome calibration of the sensor is needed. Further research showed that it is not always a reliable humidity sensor and probably should be replaced by the more expensive DHT22 or other alternatives. We kept the sensor in the setup, however no decision has been based on its data.
- Moisture sensor
We tried two types of moisture sensors. A resistance based sensor and a capacitive sensor. The electrodes used for the resistance sensors interact with the water in the soil as current flows. This pollutes the soil and destroys the sensor over time. Performing only sporadic measurements postpones this effect, however it cannot be avoided. Capacitive sensors do not interact with the soil as they measure the humidity through the capacity of the soil, not its resistance. So no current flows through the soil and there are no metallic or corrosive electrodes.

The resistance based sensor consists of two parts, the resistance probe (YL-69) and a control board (YL-38). The probe will be put into the measured soil, while the board should stay dry. It provides an analog signal. The ATmega328 has a 10 bit ADC, so the result read from the ADC is an integer between 0 and 1023.

The test showed that in a dry state the sensor shows 1023. Connecting the electrodes with a finger leads to a value around 1000.

2

Also in dry soil the readout is 1023, but as we pour water into the pot, it continuously decreases down to a few hundred.

We might have to calibrate the moisture levels for different flower or soil types, but in general the sensor seems to do the job very well.

The capacitive sensor used is the SEN0193. It is handled the same way as the YL-69 sensor on the software side, however it does not influence the soil.

- Brightness sensor
To gather information about the brightness in the environment, a photoresistor has been used. This is a semiconductor that reacts to light. The manual of the sensor suggested the range of the photoresistor is between 500Ω (bright) and 50kΩ (dark). Further it suggested to use a 1kΩ resistor for the voltage divider. An arduino tutorial
[1] suggested 10 kΩ. So we decided to measure the actual resistor values and use the formula from the lecture to calculate the matching resistor of the voltage divider.

The measurements showed that the actual photoresistor range is 500Ω to 1.7MΩ.

R1 =

p
Rmax ∗ Rmax =

√

500 ∗ 1700000 = √
850000000 = 29kΩ (1)

The closest resistor available to us was 26kΩ.
These values differ to those suggested by the tutorials, but since also the photoresistor has different values, our choice seems feasible. Also we are convinced a higher resistor will not harm the components and result in lower power consumption in contrast to a small resistor.
So we connected the chosen pulldown resistor between ground and an ADC pin of the Arduino. To complete the voltage divider the photoresistor was connected between VCC and the ADC pin.

The sensor worked very well in the tests and showed a value between 30 (covered sensor) and 950 (next to a light bulb). That confirmed our choice of the resistor.

- Battery Voltage Sensor
As the sensor node is powered by a battery it is good to have information about the battery status. This can be done by measuring the voltage of the battery via a voltage divider. There are two ways of setting the voltage reference of the ADC unit. Either the VCC of the ATmega or the internal reference voltage of 1.1V can be used. The former has the advantage of higher accuracy, assuming a stable supply voltage. However a supply voltage lower than 3.3V cannot be measured correctly. Notice that the ATmega328 will continue to operate even at a supply voltage as low as 2.7V, although some external components might fail. The second version has the advantage that also supply voltages below 3.3V can be measured, however it has to be calibrated for each ATmega individually to be as precise.

3

In any case a voltage divider is needed to convert the voltage from 0-6V to 0-3.3V respectively 0-1.1V. The design of the voltage divider is a tradeoff between measurement precision and power consumption. [2] If its total resistance is low, the power consumption of the voltage divider is too high for a low power device. If the resistance is too high, the measurement will become unstable and a capacitor becomes necessary to smooth the measurements. We decided to use a resistance of 100kΩ between GND and the ADC pin as well as 500kΩ between VCC and the ADC pin. This seemed to be a good trade-off without requiring a capacitor.

### 2.1.1 Low Power Capability

As mentioned before, the Arduino Mini 3.3V 8MHz is the basis of our sensor node platform. However the Arduino uses about 6 mA in standby. With this current consumption a set of batteries (assuming a capacity of 2000mAh) would be empty within 14 days. In a network consisting of 7 sensor nodes, every second day batteries would be needed to be changed. This motivates to look into further power saving techniques for the Arduino.

### 2.1.2 Power supply

One of the obvious questions is the supply of the operating voltage. It has been looked into the following options:

- Using the Arduino voltage regulator The Arduino board can be powered directly from the battery and generate its own supply voltage. However this regulator is very inefficient.
- Using an external voltage regulator A more efficient external regulator can be used instead of the onboard regulator. The original regulator will still consume a small current, even if not used. Therefore it should be removed in this case. The external regulator will require a supply voltage of typically 100-200mV above the output voltage. The regulator tested by us, MCP1700-3302E, needs 3.5V, so in case of three batteries this is 1.17V per battery.
During the discharge process of a battery its output voltage drops. Once the voltage drops under the required supply voltage of a voltage regulator, the output voltage of the regulator will not match 3.3V anymore.
Figure 1 illustrates the battery voltage of a AA NiMH battery over different loads. It is important to notice that with a low load the ampere hours obtained from the battery increases. So decreasing the current used by the system by half results in more than just doubled battery life. In our application the load is less than 1mA with some 15mA pulses during data transmission. This is even far less than the uppermost

4

line indicates. It can be concluded that the energy remaining in the battery once its voltage drops below 1.17V is less than 400mA.

- Using a buck-boost converter A conventional voltage regulator needs a supply voltage of at least little over 3.3V to provide a 3.3V output. A buck-boost converter like the Pololu reg 12a which we tested, can convert voltages above 0.5V to constant 3.3V.
This is beneficial because of the dropping battery voltage during the discharge process. A buck-boost converter has a lower required supply voltage (0.5V) and therefore gets nearly all energy out of the battery. However it turned out that for very low currents, like in our sensor node, the power consumed by the Pololu is much higher than for the linear voltage regulator. This diminishes the advantage of the Pololu and even turns it into the worse choice in terms of energy efficiency. Regarding costs the linear power regulator beats the pololu by an order of magnitude.

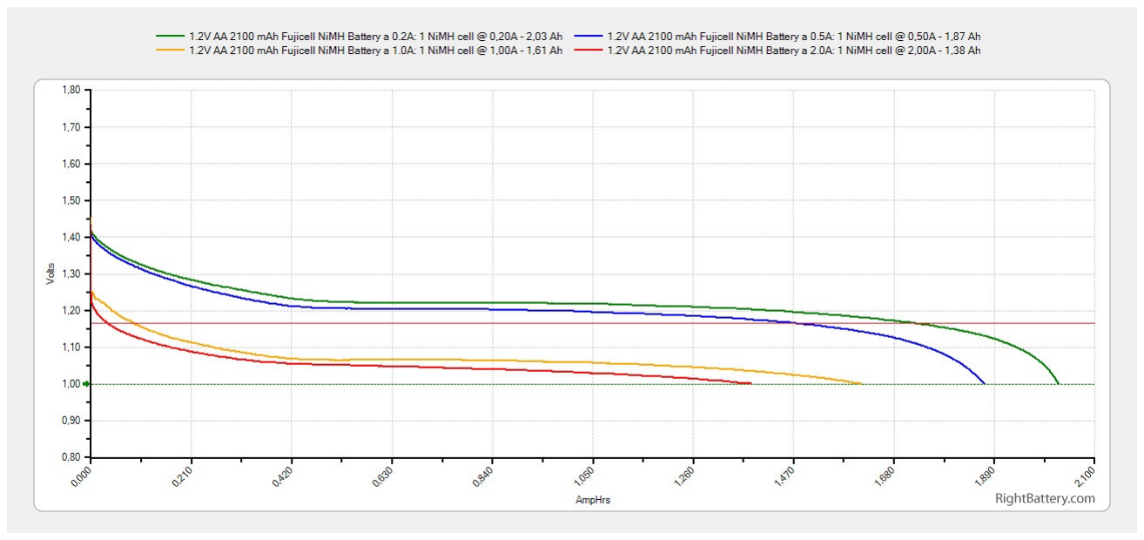
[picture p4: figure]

Figure 1: Discharge curves over different currents

We tried all solutions in our tests, however for the final solution we recommend the linear voltage regulator with adequate batteries (3 x 1.5V or 4 x 1.2V).

### 2.1.3 Power consumption optimizations

To make the batteries last as long as possible, the node should use as little power as possible.
The biggest power safer is to put the microcontroller and all peripheral devices including all sensors into sleep mode as much as possible.
This reduces the power of the system to around 1.5mA and gives 8 weeks of battery life

5

per node. This is a big improvement, however far away from a convenient solution and the technical limits.
One further optimization is to remove the power LED used to indicate the Arduino is running, as there is no need for it and the LED uses a lot of power. The LED can be removed by adding tin to connect both legs, heating them up uniformly and pulling away the LED with tweezers. This decreases the consumption to about 0.26 mA (45 weeks). Disabling TWI before sleep saved another 170µA.
Removing the parasiting onboard voltage regulator saved further 75µA. However de-soldering of medium sized SMD components requires special equipment, skills or patience.
The resulting consumption for the design including all final components and using the external voltage regulator is 15µA. (4.5V ==> 67.5µW) Using the Pololu the same design needs 90µA (4.5V ==> 405µW). It can be concluded that in this situation an appropriate voltage regulator is more efficient than a Pololu. Also the voltage divider is a far cheaper solution.

Battery One crucial factor obviously is the kind of battery itself. The following summarizes the key issues of batteries in our application.

- Voltage
It must be mentioned that every battery type operates at a different voltage, what has to be considered at the choice of battery. Three 1.5V alkaline batteries have been assumed in the calculations above, resulting in 4.5V total. Using rechargeable batteries with 1.2V each, like nickel metal hydride batteries, the resulting total 3.6V are just slightly above the threshold for the voltage regulator to operate, so they will fail very soon. In this case the Pololu would have the better performance. For operation with the voltage regulator 3x1.5V LSD NiMH batteries or 4x1.2V rechargeable alkaline batteries are recommended.
- Capacity
Obviously batteries with higher capacity last longer without replacing them.
- Temperature range
Not all batteries withstand extreme temperatures. For example conventional NiMH batteries are not supposed to be used in cold environments, while their self-discharge rate drastically increases at high temperatures. LSD NiMH however can resist cold temperatures.
- Self discharge rate
Conventional NiMH batteries have a high self discharge rate. Even if not used, they loose half their energy after one month. Low self discharge NiMH (LSD NiMH) batteries loose only a fraction of this energy per month (< 3%) and can be used for several years without recharging.

6

### 2.1.4 PCB

In order to incorporate all components into a small box, a PCB has been designed by our supervisor using the Fritzing tool. The yellow traces are on the top side and the orange traces on the bottom. To offer flexibility with the power supply of the sensors, it can be selected whether they should be powered by the normal VCC pin or powered by an arduino pin to be able to deactivate all sensors during low power phases. The board has been produced by the Fritzing company tested with our software. It works as expected.

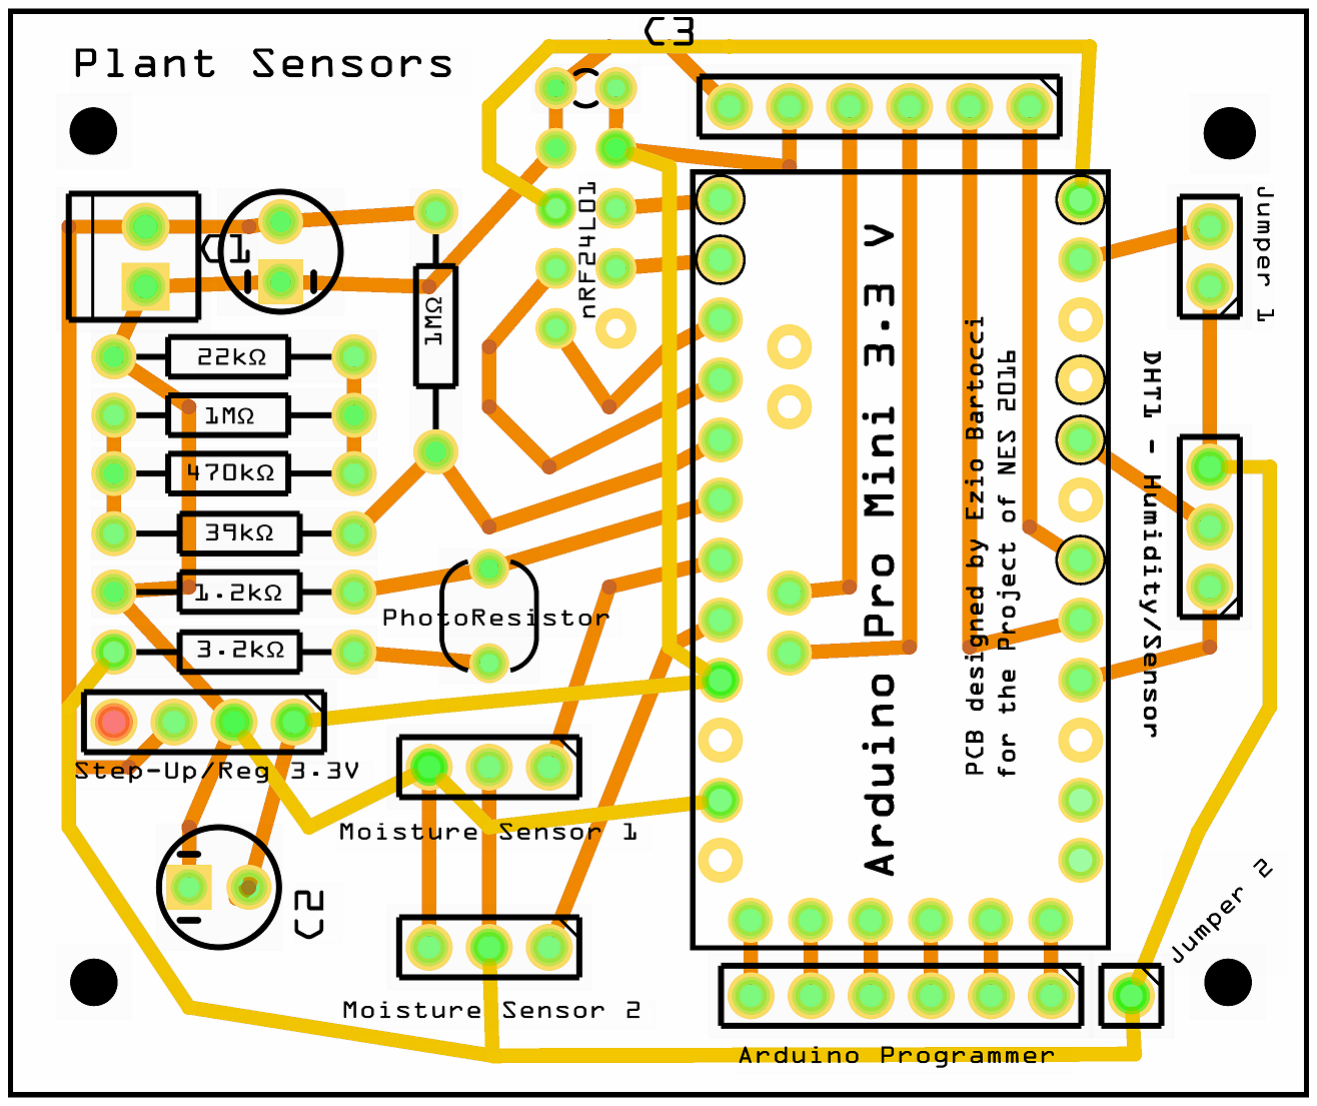
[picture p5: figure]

Figure 2: PCB design of the sensor node.

### 2.1.5 Data storage

As the communication between a sensor node and the controller might be faulty, the data shouldn’t get lost. If the sensor node sends data to the controller and doesn’t get a response, the data is stored in the EEPROM of the sensor node until the controller requests the data. The size of the EEPROM is limited to 1KB, therefore only around 25 data sets fit into the storage. Another issue with using EEPROM as storage is that the write cycles it endures are limited. Therefore an algorithm has been developed to ensure equal wearout of the EEPROM cells. In case the controller does not request the data and the EEPROM memory is full, the oldest data in the storage is replaced with the most recent data.

7

8

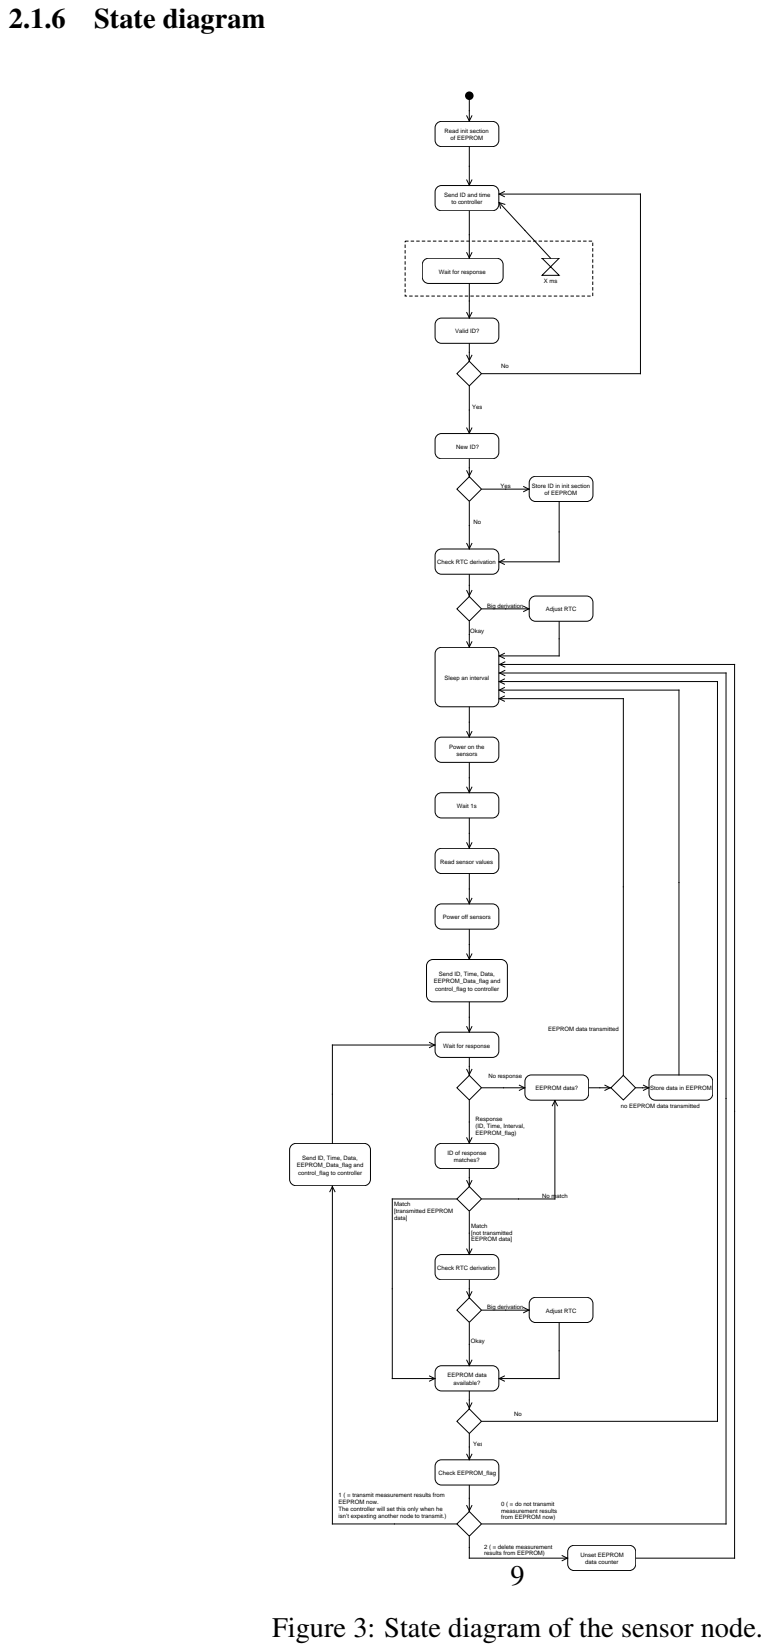
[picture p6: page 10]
2.1.6 State diagram; EEPROM data?; Valid ID?; Unset EEPROM data counter; Check EEPROM_flag; EEPROM data available?; Adjust RTC; Wait 1s; New ID?; No response; Yes; Match [transmitted EEPROM data]; Okay; Big derivation; Match [not transmitted EEPROM data]; No match; Response (ID, Time, Interval, EEPROM_flag)

Read init section
of EEPROM

Send ID and time
to controller

Wait for response

Store ID in init section

Check RTC derivation

Sleep an interval

Power on the
sensors

Read sensor values

Power off sensors

Send ID, Time, Data,
EEPROM_Data_flag and
control_flag to controller

EEPROM data transmitted

Store data in EEPROM

no EEPROM data transmitted

ID of response
matches?

1 ( = transmit measurement results from
EEPROM now.
The controller will set this only when he
isn't expexting another node to transmit.)

0 ( = do not transmit
measurement results
from EEPROM now)

2 ( = delete measurement
results from EEPROM)

Figure 3: State diagram of the sensor node.

### 2.2 Controller

The controller keeps track of all nodes and handles their registration. It coordinates the communication of the sensor and pump nodes and maintains a schedule of which node is allowed to transmit at which time. The controller also executes the watering policy that the user has selected for each flower. For this task it wirelessly communicates with the sensor nodes situated in the flower pots and the pump nodes situated next to the water tanks. The sensor nodes provide the controller with the most recent measurement values, whereas the pump nodes executes the pump commands received from the controller. The controller also provides an interface for the front end to get the newest data and to perform certain actions. It was a restriction to use the Particle Photon as controller hardware.

### 2.2.1 State diagram

States:

- Check pending tasks

This is the begin of the loop() Function. The controller will always come back to this state to check which tasks are pending. The following actions are possible:

– A NRF24 message is arrived, process this message.

– Also if an interactive command has arrived via the IOT framework, this command has to be processed. (Typically sending an instruction to a Motor Node)

– If, according to the watering schedule, a pump node should take an action now, the controller goes to the “Send Watering Command to Motor Node” state

– If a Motor Node did not respond as expected, an error handling sequence should be started (writing to log and if needed respond to the IOT framework)

- Send Watering Command to Motor Node Whenever the controller decides a pump node should start to pump, this function is called. It prepares and sends a message to concerned the pump node. It also writes the message content to a log file.
- Write Pump Node Timeout to Log If a pump node does not reply within the specified timeout duration, an entry into the log file has to be written. In case the command of the concerned message has been triggered by the IOT framework, the controller will move to the “Send Error Notification to App” state. Otherwise it enters the “Reschedule Watering” state.
- Send Error Notification to App If a IOT command could not be successfully executed, the IOT framework has to be notified about the problem. Afterwards the controller goes back to checking for pending tasks.

10

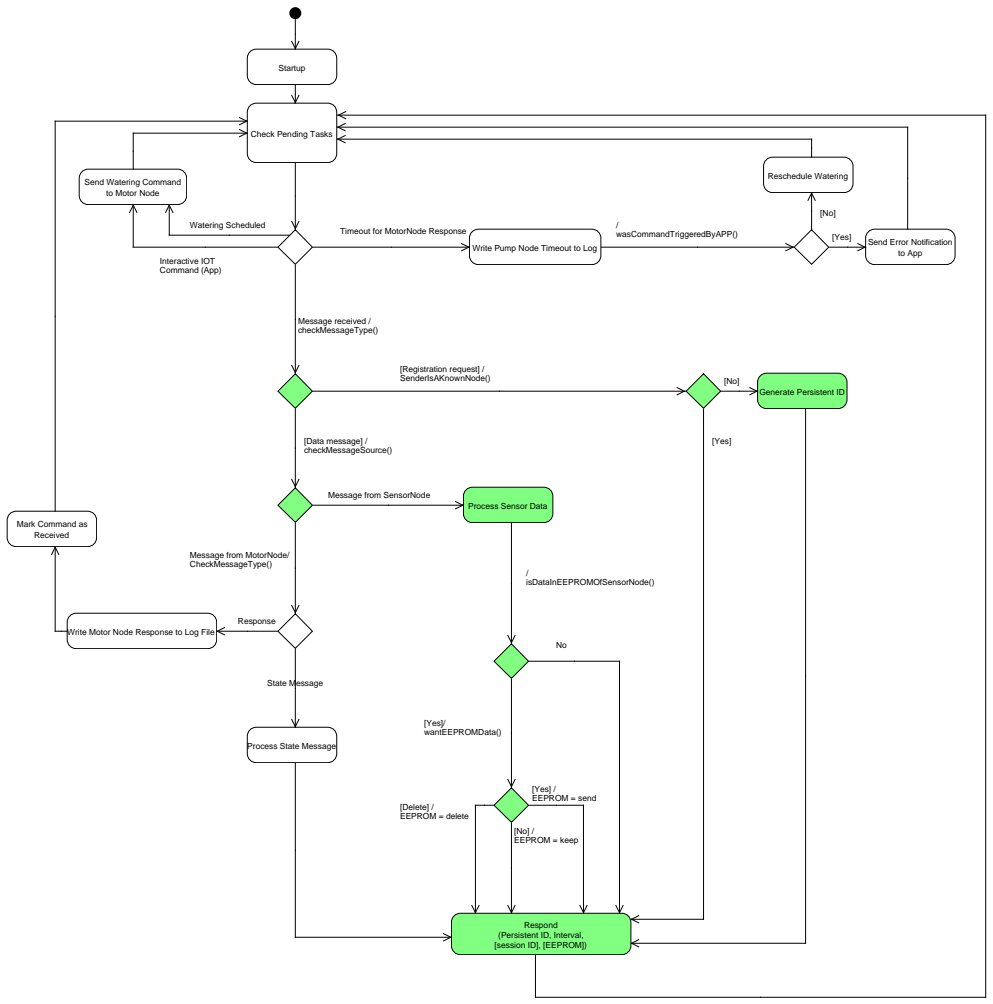
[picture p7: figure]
Write Motor Node Response to Log File; Reschedule Watering; Send Error Notification to App Write Pump Node Timeout to Log; Send Watering Command to Motor Node; Process Sensor Data; Respond (Persistent ID, Interval, [session ID], [EEPROM]); Generate Persistent ID; Process State Message; Mark Command as Received; Check Pending Tasks; Startup; / wasCommandTriggeredByAPP(); / isDataInEEPROMOfSensorNode(); Message received / checkMessageType(); Timeout for MotorNode Response; [Registration request] / SenderIsAKnownNode(); [Yes]; Watering Scheduled; Interactive IOT Command (App)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

Figure 4: State diagram of the controller.

- Reschedule Watering If a scheduled watering task failed, the controller needs to reschedule this watering task. There are many possible algorithms for this such as:

– Skip this watering task and proceed as usual

– Retry the watering task a certain number of times. If it fails, proceed as usual

– Reschedule the watering of this pump node in a given fashion.

For a first version it is sufficient to skip the watering, if it failed.

- Write Motor Node Response to Log File If a motor node responds to a control command, this response has to be logged to a log file. Afterwards the controller processes the response.

11

- Mark Command as Read The watering command is marked in the controller internal command list as “read by the node”. Otherwise a timeout would occur.
- Process State Message As the pump node finished to pump, it will send a state message to the controller indicating the end of the pump sequence. This message can be responded to by the controller, but it doesn’t have to be.
- Process Sensor Data When the controller receives data from a sensor node, it stores the data. Later this data will be used for the watering algorithm and statistical analysis. Afterwards it will check whether the sensor node has data stored in its EEP-ROM. This will be the case if the controller was unavailable to the sensor node for some time. If there is EEPROM data the controller can choose whether it wants the data to be transmitted now, later or not at all. If the latter is the case, the node will delete its sensor data. If the controller has currently time to receive the EEPROM data, it should request it. Otherwise the data might get lost. If there is a lot of traffic scheduled in the next slots, the controller can postpone the EEPROM data transmission. In this case the next sensor node transmission should be scheduled in a slot that is followed by empty slots. This way it is guaranteed that there is enough time to transmit all EEPROM data.
- Respond In the respond state a response is prepared and sent to the node from which the last message has been received. Its content is based on the previous states.

### 2.3 Pump Node

The purpose of the pump node is to serve as an actuator and activate a pump for a specified time on request of the controller. An early draft involved a 3d printed reservoir where the electronics would be incorporated. However it turned out to be inflexible and therefore only the pump mountings have been printed and the mountings are attached to a bucket. From that bucket a hose leads to the pump and further to the flower. It was required that the pump node supports two pumps which can be activated individually. Since the ATmega itself cannot provide sufficient current to power the pumps, a relay is used for each pump. A specific protocol takes care of the reliable communication between the pump node and the controller. It has been carefully designed to avoid freezing of the node and to ensure reliable operation of the pumps.

### 2.3.1 Actuator

As the task of the pump node is to water flowers, it is equipped with two pumps. Alternatively solenoid valves have been considered, however pumps are easier to use and a reliable solution. The chosen peristaltic pumps require high currents around 200mA and

12 a voltage of 12V. Therefore they cannot be powered by Arduino pins, but have to be powered from an own power source like a voltage booster or an additional power supply. We chose an external 12V power supply to power the node. The Arduino switches two relays which in turn power the pumps. As high current is needed, the pumps are not activated concurrently, but sequentially. They typically will be active for around 30 seconds. Figure 5 illustrates a pumpnode with one pump.

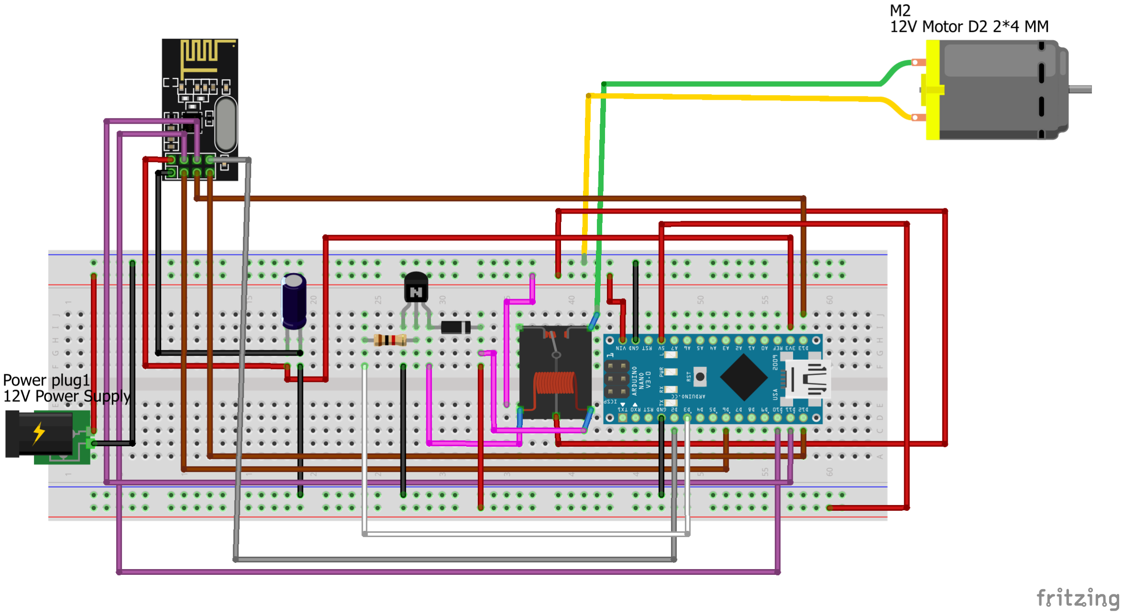
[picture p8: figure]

Figure 5: Breadboard schematic of the pump node.

### 2.3.2 Fall-back Mode

To guarantee a dependable solution resistant to external factors such as a failing internet connection or wireless jamming attacks, a fall-back mode has been implemented to water the flowers reliably, even if the control node is unavailable.

For this purpose the pump node uses all incoming messages, also those addressed to other nodes, to detect the availability of the controller. If the pump node does not receive any messages from the controller for a specified timeout_duration, it assumes the controller is offline and goes into a fall-back mode.

The parameters for the fall-back mode are:

- timeout_duration
- enable

13

- time
- watering_duration

These parameters can be set at the IOT front-end-interface and get transmitted to the pump nodes by the controller at the pump node registration and with every pump request. (so in case they get changed the pump node stays up to date) In case the fall-back is disabled, no action takes place if the controller is unavailable. In case the fall-back is enabled and the controller is unavailable, daily at the specified time the pump node pumps for the specified watering_duration.

This mechanism does not guarantee a perfect watering, however it prevents the plants from drying.

To make the fall-back visible to the monitor node, a notification message is broadcasted via the wireless network containing the timestamp, pump duration and last timestamp from a controller message.

### 2.4 Protocol

The application itself and project requirements bring certain constraints regarding the system architecture and protocol. For communication XBee, WiFi and RF24L01 chips have been considered. Because of costs, power and sensor constraints XBee and WiFi turned out to be not feasible.

Sensor Node <–> Controller One main constraint is that the sensor nodes should not be connected by cables. Therefore the communication with the controller has to be wireless and the node cannot be powered by the power grid. For receiving messages on a wireless interface, the wireless module has to be actively listening continuously. The chosen modules RF24L01+ use about 15mA in listening mode. That makes a controller initiated communication impossible, as the constantly activated listening mode of the RF module would drain the batteries within 5 days. To solve this problem, we chose that the sensor node initiates the transmission, waits for the answer of the controller and puts the RF module to a low power mode. This is an elegant solution for keeping the power down, however it is much more difficult to implement. It makes it necessary that every sensor is assigned a precise time at which it is expected to send its next measurement data to the controller in advance. Therefore the controller has the task of coordinating these timeslots and synchronizing the clocks of the sensor nodes. New sensor nodes should automatically be integrated into this schedule.

For registering nodes and perform data exchanges a protocol has been developed. The developed library provides access to the protocol registers to use the functionality of the protocol.

14

Status register in the node –> controller message:

Bit | name | description | 0 - meaning | 1 - meaning
0 | RTC_RUNNING_BIT | RTC is paired on the node | no RTC | RTC paired
1 | MSG_TYPE_BIT | type of message | registration request | data
2 | NEW_NODE_BIT | new or known node | known node | new node
3 | EEPROM_DATA_AVAILABLE | is data in the EEPROM | no data | data available
4 | EEPROM_DATA_PACKED | kind of data | live data | EEPROM data
5 | EEPROM_DATA_LAST | more EEPROM data pending | more data | not more data
6 | NODE_TYPE | type of node | sensor node | pump node

Status register in the controller –> node message:

Bit | name | description | 0 - meaning | 1 - meaning
0 | REGISTER_ACK_BIT | registration acknowledge | no reg | registration
1 | FETCH_EEPROM_DATA1
2 | FETCH_EEPROM_DATA2
3 | ID_INEXISTENT | id invalid | id valid | id invalid
7 | ID_REGISTRATION_ERROR

Further the combination “00” in the FETCH_EEPROM_DATA1/2 bits indicates the EEPROM data shouldn’t be transmitted now, “01” means the sensor node should send the data now and “10” means the node should delete the stored EEPROM data.

### 2.5 Pinout

To quickly change the role of an ardunino, it is a good idea to have a standardized pinout for all sketches. The following tables summarize the pinout.

Digital Pins:

| 2 | 3 | 4 | 5 | 6 | 7 | 8 | 9-13
Controller | DS_1302 | DS_1302 | DS_1302 | | | Button | RTC_PWR | RF24
SensorNode | DS_1302 | DS_1302 | DS_1302 | DHT11 | | Button | SENS_PWR | RF24
PumpNode | | | | Pump1 | Pump2 | Button | | RF24
Particle | ??

Analog Pins:

### 2.6 Front-End

In order to adjust, maintain and control the system, it is necessary to have direct access to certain features. As it is not feasible to interact with the Photon or an Arduino a front-end

15

| A0 | A1 | A2 | A3 | A4 | A5 | A6 | A7
Controller | | | | | DS_3231 | DS_3231
SensorNode | Battery | Light | Moisture1 | Moisture2 | DS_3231 | DS_3231
PumpNode
Particle

has been developed. Note that the functions offered by the front-end are also accessible through console.particle.io or the Particle app. However the front-end is more user friendly. The front end offers the possibility to mate a sensor node with a pump node, to see the sensor data of a particular node and to manually start the watering of a flower pot. This chapter can be considered as a user guide for operating the whole system. In the following the features are introduced with an example each.

### 2.6.1 Mapping

For watering the flowers the system needs to know which sensors monitor which flowers. This is called the mapping and can be done via the front end. Each pump node can support up to two pumps and every sensor node can own up to two moisture sensors. A word of warning: It is important to make sure to chose the right pump and the right sensor, otherwise the flower might not be watered, but the floor instead.
A pump does not need to be mapped and a moisture sensor does not need to be mapped to. To map a pump node to a sensor node they have to be selected in the drop down list. Further the user has to chose which moisture sensor should be and which pump should be mapped. An example is shown in the following figure.

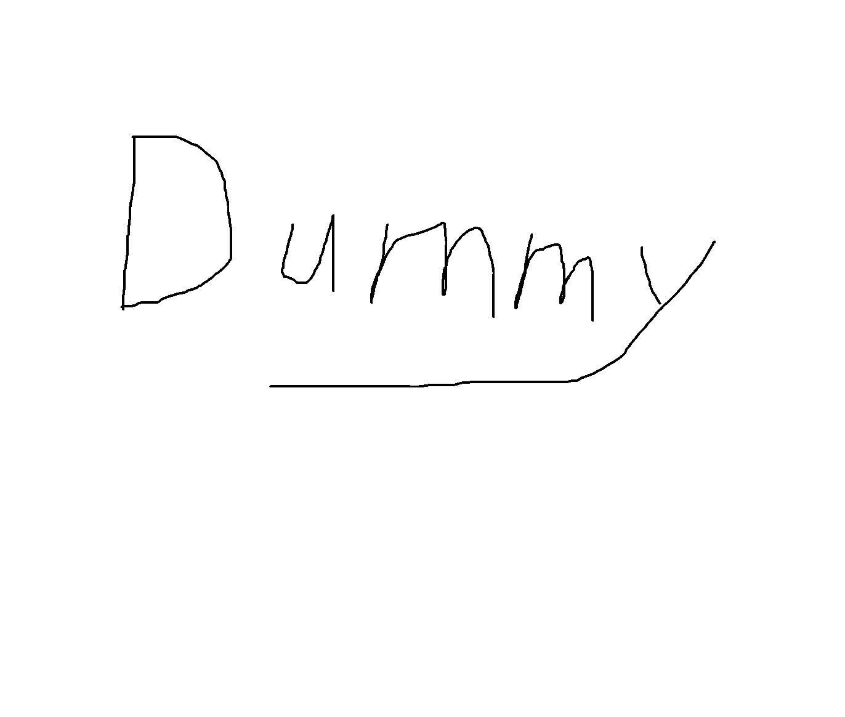
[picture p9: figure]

Figure 6: How to map a pump to a moisture sensor.

### 2.6.2 Sensor View

To monitor the most recent environment values, all sensor data can be listed in the front end.

16

Figure 7: Overview of the sensor data.

### 2.6.3 Manual Watering

Under special circumstances one might decide to manually add some water to a flower. In this case the front end offers a comfortable way to do so. The user only has to chose the flower from the drop down menu and how long the water should be running. (in seconds) The following figure shows an example.

Figure 8: How to manually water a flower.

### 2.7 Data logger

The data logger logs the data...

17

## References

[1] Arduino Playground. http://playground.arduino.cc/Learning/PhotoResistor.
[2] Jeelabs.org. http://jeelabs.org/2013/05/16/measuring-the-battery-without-draining-it/.

18

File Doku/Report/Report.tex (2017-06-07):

\documentclass[12pt,a4paper,titlepage,oneside]{article}
\usepackage[utf8]{inputenc} 
\usepackage[T1]{fontenc}
\usepackage{protocol}
\usepackage{listings}
\usepackage[T1]{fontenc}
\usepackage{times}
\usepackage{epsfig}
\usepackage{epstopdf}
\usepackage[german, english]{babel}
\usepackage{listings}
\usepackage{textcomp}
%\usepackage[normalem]{ulem}
\usepackage{tabularx}
\usepackage{amssymb,amsmath}
\usepackage{color}
%\usepackage{framed}
\usepackage{makeidx}
\usepackage{natbib}
\usepackage{textcomp}
\usepackage{alltt}
\usepackage{array}
\usepackage{rotating}
\usepackage{lscape}
\usepackage{graphicx}
\usepackage{import}
\usepackage{circuitikz}
\usepackage[bookmarks]{hyperref}
\usepackage{float}

\usepackage{verbatim}

%%%%%%%%%%%%%%%%%%%%%%%%%%%%%%%%%%%%%%%%%%%%%%%%%%%%%%%%%%%%%%%%%%%%%%%%%%%%%%%%%%%%%%%
% Alter some LaTeX defaults for better treatment of figures:
    % See p.105 of "TeX Unbound" for suggested values.
    % See pp. 199-200 of Lamport's "LaTeX" book for details.
    %   General parameters, for ALL pages:
    \renewcommand{\topfraction}{0.9}	% max fraction of floats at top
    \renewcommand{\bottomfraction}{0.8}	% max fraction of floats at bottom
    %   Parameters for TEXT pages (not float pages):
    \setcounter{topnumber}{2}
    \setcounter{bottomnumber}{2}
    \setcounter{totalnumber}{4}     % 2 may work better
    \setcounter{dbltopnumber}{2}    % for 2-column pages
    \renewcommand{\dbltopfraction}{0.9}	% fit big float above 2-col. text
    \renewcommand{\textfraction}{0.07}	% allow minimal text w. figs
    %   Parameters for FLOAT pages (not text pages):
    \renewcommand{\floatpagefraction}{0.7}	% require fuller float pages
	% N.B.: floatpagefraction MUST be less than topfraction !!
    \renewcommand{\dblfloatpagefraction}{0.7}	% require fuller float pages

	% remember to use [htp] or [htpb] for placement
%%%%%%%%%%%%%%%%%%%%%%%%%%%%%%%%%%%%%%%%%%%%%%%%%%%%%%%%%%%%%%%%%%%%%%%%%%%%%%%%%%%%%%%

%"C:\Program Files\MiKTeX 2.9\miktex\bin\pdflatex.exe" main.tex

\lstset{
  backgroundcolor=\color{lbcolor},
  tabsize=4,
  rulecolor=,
  language=C, %VHDL
  basicstyle=\scriptsize,
  upquote=true,
  aboveskip={1.0\baselineskip},
  columns=fixed,
  showstringspaces=true,
  extendedchars=true,
  breaklines=true,
  prebreak = \raisebox{0ex}[0ex][0ex]{\ensuremath{\hookleftarrow}},
  frame=single,
  showtabs=false,
  showspaces=false,
  showstringspaces=false,
  identifierstyle=\ttfamily,
  keywordstyle=\color[rgb]{0,0,1}\ttfamily,
  commentstyle=\color[rgqb]{0.133,0.545,0.133}\ttfamily,
  stringstyle=\color[rgb]{0.627,0.126,0.941},
  numberstyle=\colr{black}\ttfamily,
}
\definecolor{listinggray}{gray}{0.9}
\definecolor{lbcolor}{rgb}{0.97,0.97,0.97} %gray
%\definecolor{lbcolor}{rgb}{1.0,1.0,1.0} %white

\definecolor{myyellow}{rgb}{1.0,1.0,0}
\definecolor{mygray}{rgb}{0.5,0.5,0.5}
\definecolor{mylime}{rgb}{0.6,1.0,0.2}
\definecolor{mycyan}{rgb}{0.0,1.0,1.0}

\definecolor{green}{RGB}{0,255,0}

\sloppy

\exercise{
  {\huge Network Embedded Systems [VU]} 
  \par
  {\huge Semster Project - Protocol}
  \par
}
% fancy projektname fehlt noch..wem fällt was ein??

\authors{
  Helmut Bergmann, Matr.Nr. 0325535  \par
  {\small 0325535@student.tuwien.ac.at} \par
  Bernhard Fritz, Matr.Nr. 0828317  \par
  {\small 0828317@student.tuwien.ac.at} \par
  Marko Stanisic, Matr.Nr. 0325230 \par
  {\small 0325230@student.tuwien.ac.at} \par
}

\begin{document}

 \newcolumntype{C}{>{\centering\arraybackslash}p{4em}}
 
\maketitle
%\tableofcontents
%\clearpage

\pdfinfo{
   /Title  (Sensor Testing 1 - Protocol)
   /CreationDate (\today)
%   /Subject ()
%   /Keywords ()
}

%\cite{sharc_hw_ref}
%\cite{sharc_prog_ref}
%\cite{ezkit_manual}

%-----------------------------------------------------------------------------
%   content
%-----------------------------------------------------------------------------
% Introduction about the project etc...
Everyday life brings many repetitive tasks. As technology increases also more complicated tasks can be automatised, relieving humans from repetitive tasks. In our project we want to develop a system that handles the watering of plants in order to decrease the number of routine tasks done in a household and also to reliably continue watering even if no person is at home for a longer period of time.

\section{Requirements}
\input{Requirements.tex}

\section{Design}

\subsection{Sensor Node}
\input{SensorNode.tex}

\subsection{Controller}
\input{Controller.tex}

\subsection{Pump Node}
\input{PumpNode.tex}

\subsection{Protocol}
\input{Protocol.tex}

\subsection{Pinout}
\input{Pinout.tex}

\subsection{Front-End}
\input{FrontEnd.tex}

\subsection{Data logger}
\input{Datalogger.tex}

\subsection{Problems}
\input{Problems.tex}

%-----------------------------------------------------------------------------
%   bibliography
%-----------------------------------------------------------------------------

\clearpage 
\phantomsection
\addcontentsline{toc}{section}{References}
\bibliographystyle{plain}
\bibliography{references}
\printindex
\printindex

\end{document}

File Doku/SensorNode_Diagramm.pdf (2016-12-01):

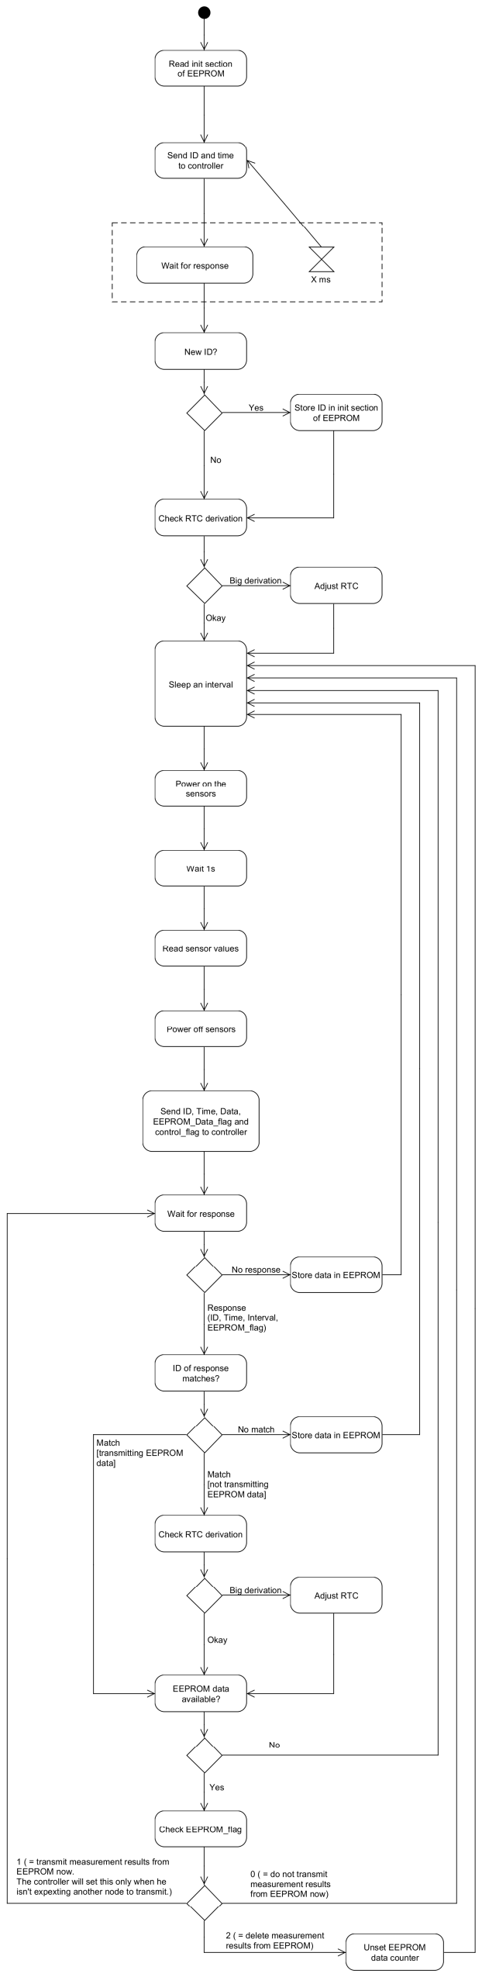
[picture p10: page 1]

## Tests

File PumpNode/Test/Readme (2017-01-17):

SimpleRF:
Minimum communication, test if my hardware is ok.

turnOnOff:
A basic software whic tests to turn on the motor pump by switching the relay

turnOnOff_RF:

turnOnOff_RFv2:
Controller sends an integer variable beginnig from 1 , every cycle
the pump node takes the received integer variable and turns the pump on.
The integer variable are the amount of time to turn on the pump.

turnOnOff_RFv3:
Same as turnOnOff_RFv2, but the PumpNode goes into sleep mode and wakes up 
if a message arrives, so we care about interrupts

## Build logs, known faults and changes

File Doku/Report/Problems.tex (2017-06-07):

% No precise requiremens
% Particle framework is buggy. That makes debugging difficult.
% Paricle is not reliable. WiFi connection is lost sometimes
% RF24 is not reliable
% Wackelkontakte
% low power hat viel zeit gekostet
% Protokoll debuggen hat viel zeit gekostet

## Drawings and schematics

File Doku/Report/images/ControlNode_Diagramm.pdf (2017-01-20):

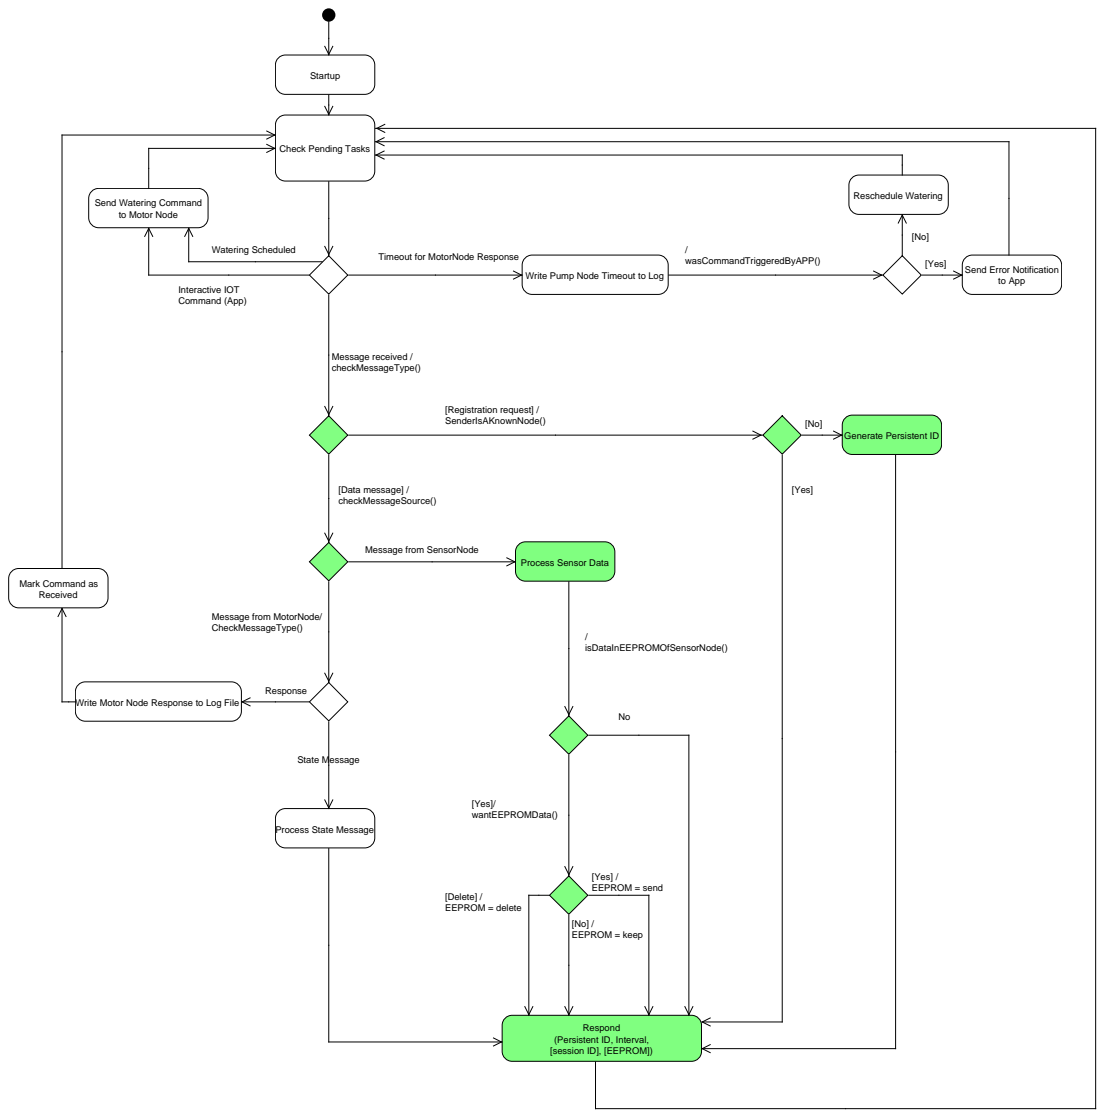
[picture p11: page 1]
Reschedule Watering; Startup; / wasCommandTriggeredByAPP(); / isDataInEEPROMOfSensorNode(); Message received / checkMessageType(); [Registration request] / SenderIsAKnownNode(); [Yes]; Watering Scheduled; Interactive IOT Command (App); [No] / EEPROM = keep; [Delete] / EEPROM = delete; [Yes] / EEPROM = send; [Yes]/ wantEEPROMData(); Response; [Data message] / checkMessageSource(); State Message

Check Pending Tasks

Send Watering Command
to Motor Node

Timeout for MotorNode Response

Send Error Notification

to App Write Pump Node Timeout to Log

Generate Persistent ID

Message from SensorNode

Process Sensor Data

Mark Command as
Received

Message from MotorNode/
CheckMessageType()

Write Motor Node Response to Log File

Process State Message

Respond
(Persistent ID, Interval,
[session ID], [EEPROM])

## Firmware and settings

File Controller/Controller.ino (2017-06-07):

/*
Project:  NESE_Blumentopf
File:     Controller.ino
Authors:  Bernhard Fritz  (0828317@student.tuwien.ac.at)
Marko Stanisic  (0325230@student.tuwien.ac.at)
Helmut Bergmann (0325535@student.tuwien.ac.at)
The copyright for the software is by the mentioned authors.

The purpose of the module is to coordinate the network of
wireless nodes and to connect it to the IOT platform.
The controller module can run on an Arduino or Particle Photon.
Therefore the corresponding flags (HW, HW_RTC, SD_AVAILABLE, etc.) have to be set in the header file.

*/
//#include <SPI.h>
#include "Blumentopf.h"
#include <LinkedList.h> //for PumpHandler List


#if (SD_AVAILABLE == 1)
#include <SD.h>
#endif


/**some declarations for the RTC , in case we have a RTC*/


#if (HW_RTC == RTC_1302)
RTC_DS1302 myRTC(2, 3, 4);  // CE, IO, CLK (RST, DAT, CLK)
#elif (HW_RTC == RTC_3231)
RTC_DS3231 myRTC;
#elif (HW_RTC == RTC_3232)
RTC_DS3232 myRTC;
#endif

#if (DEBUG_>0)
uint32_t time_;
uint16_t nDummyCount=0;
#if(DEBUG_TIMING_LOOP > 0)
long unsigned duration_loop=0;
long unsigned duration_max=0;
long unsigned duration_tmp=0;
long unsigned duration_sending=0;
#endif

#endif

//#define INTERVAL (600)


struct Data myResponse; //32byte
struct Data myData; //32byte
#if (TEST_PUMP==0)
class CommandHandler myCommandHandler;
#endif
//marko@: wozu brauchen wir diese variable?
//verwende sie jetzt Um Pumphandler zu zählen

uint16_t nPumpHandlerCnt=0;
/*Marko@: introduced for increasing communication reliability by redundance
*        important for Pump Handler,  instead waiting for acknowledgment
*        we resend a message to ensure that at least one message arrives desination
*        maximum resend count defined in RADIO_RESEND_NUMB
*/
uint8_t write_cnt=1;
/*
*
*/
bool bResponseNeeded = true;


#if(HW==HW_PHOTON)
/* Hardware configuration: Set up nRF24L01 radio on SPI bus plus pins 7 & 8 */
//function to initiate radio device with radio(CE pin,CS pin)
RF24 radio(PHOTON_CS_PIN,PHOTON_CE_PIN);

#else
RF24 radio(CE_PIN, CS_PIN);
//#define LED_BUILTIN D13 is already defined in Arduino.h
#endif

//brauchen wir 3 pipes!!!!!!!!!!??
//const uint64_t pipes[3] = {0xF0F0F0F0E1LL, 0xF0F0F0F0D2LL, 0xE8E8F0F0E1LL}; // pipe[0] ist answer-channel
const uint64_t pipes[2] = {0xF0F0F0F0E1LL, 0xF0F0F0F0D2LL};//didn't reduce dynamic memory usage
nodeList myNodeList;
LinkedList<PumpNode_Handler*> PumpList = LinkedList<PumpNode_Handler*>();

#if TEST_PUMP
uint16_t nTestWatering = 1000;
uint8_t i_=0;
uint8_t i_2=0;
#endif


#ifdef PARTICLE_CLOUD

  /**************PARTICLE CLOUD*****************************************/
  HomeWatering* myHomeWatering;
  /**********************************************************************/
#endif


/*
SETUP

PREREQUISITE:
EEPROM: every byte in the EEPROM must be initialized with 0xff
(only,if you use the Blumentopf library the first time)
(or if you want to delete old nodes and want to start again->nodeList::clearEEPROM_Nodelist())
*/
/*******************************************************************************************/
/*******************************************************************************************/
/********************************S E T U P***************************************************/
void setup(void)
{
  DEBUG_SERIAL_INIT_WAIT;

  #if(HW==HW_PHOTON  && DEBUG_==1)

  uint16_t max_cnt=30000;
  uint32_t _timer_=millis();
  uint32_t dif=0;
  while((dif=(millis()-_timer_))<max_cnt)
  {
    if((dif>10000) && ((dif % 5000)==0))
    {
      DEBUG_PRINTLNSTR("PARTICLE PHOTON DELAYED STARTUP.................");
      DEBUG_PRINTSTR("SETUP WILL BE CONTINUED IN ");
      DEBUG_PRINT(max_cnt-dif);
      DEBUG_PRINTLNSTR(" ms.");
    }
  }
  #endif
  //Initiate Real Time Clock


  //radio.begin();
  //Marko@ : want to ensure that all three node types use the same settings
  radio.begin(RADIO_AUTO_ACK,RADIO_DELAY,RADIO_RETRIES,RADIO_SPEED,RADIO_CRC,RADIO_CHANNEL,RADIO_PA_LEVEL);
  //  radio.setRetries(15,15);
  //  radio.setPALevel(RF24_PA_MIN);//@Marko: Test other configuration, maybe better communication
  //radio.setChannel(RADIO_CHANNEL);  // Above most Wifi Channels

  //  radio.setPayloadSize(8);
  radio.openReadingPipe(1, pipes[1]);
  radio.openWritingPipe(pipes[0]);
  radio.startListening();



  DEBUG_PRINTLNSTR("\r\n****************************************************");
  /*The Photon Board is not able to print messages from Setup() from Startup
  * Some time must pass to be able to see Serial prints
  */

  #if (HW_RTC > NONE)

  #if (HW_RTC == RTC_1302)
  myRTC.init(&myData.state);
  #elif (HW_RTC == RTC_3231)
  //  #if(HW == HW_PHOTON)
  //  pinMode(D4, OUTPUT);
  //  digitalWrite(D4, HIGH);
  //  #endif
  pinMode(HW_RTC_PIN, OUTPUT);
  digitalWrite(HW_RTC_PIN, HIGH);
  delay(20);
  myRTC.init(&myData.state);
  #elif (HW_RTC == RTC_3232)
  pinMode(HW_RTC_PIN, OUTPUT);
  digitalWrite(HW_RTC_PIN, HIGH);
  delay(20);
  //Bernhard@: anschauen ob myrepsonse.state oder mydata.state
  //displayTime(RTC.get());
  /*
  tmElements_t tm;
  tm.Second=00;
  tm.Minute=25;
  tm.Hour=15;
  tm.Wday=1;   // day of week, sunday is day 1
  tm.Day=30;
  tm.Month=4;
  tm.Year=CalendarYrToTm(2017);//y2kYearToTm(2017) ;   // offset from 1970;
  //setTime(makeTime(tm));
  myRTC.setTime(makeTime(tm));
  */
  myRTC.init(&(myResponse.state));
  //  displayTime(myRTC.getTime());
  #endif

  displayTimeFromUNIX(myRTC.getTime());   // if there is a RTC --> display the time independently of the RTC type
  #endif

  //myNodeList.clearEEPROM_Nodelist();    // deletes the node list!!!!!!!!!!!!!!!!!!!!!!!!!!!!!!!!!!!!!!!!!!!!!!!!!!!!!!!!!!!!!!!!!!!!!!!!!!!!!!!!!!!!!!!!
  myNodeList.getNodeList();

  //mark every response as Controller packet
  setDATA_ControllerPacket(&myResponse);//Helmut@: for Logging
  DEBUG_PRINTSTR("[CONTROLLER]"); DEBUG_PRINTSTR("[MYRESPONSE PACKETINFO]:"); DEBUG_PRINTLN(myResponse.packetInfo);

  #if (SD_AVAILABLE == 1)

  if (initStorage() == false)
  {
    return;
  }

  DEBUG_PRINTSTR("[CONTROLLER]"); DEBUG_PRINTLNSTR("card initialized.");

  digitalWrite(12, HIGH);
  SPI.transfer(0xAA);
  #endif

  DEBUG_FLUSH;

  #ifdef PARTICLE_CLOUD
    DEBUG_PRINTLNSTR("\r\n***************with PARTICLE CLOUD********************");
    /**************PARTICLE CLOUD*****************************************/
    myHomeWatering=new HomeWatering(&myNodeList,&myRTC);
    /**********************************************************************/
  #endif

}//setup

/*
Initializes the storage for data logging
The Arduino writes to an SD card for debugging purposes,
the particle will either write to his internal memory or not log the data at all.

*/
bool initStorage()
{
  if (HW == HW_ARDUINO)             // using arduino
  {
    #if (SD_AVAILABLE == 1)
    DEBUG_PRINTSTR("[CONTROLLER]"); DEBUG_PRINTLNSTR("Initializing SD card...");

    // see if the card is present and can be initialized:
    if (!SD.begin(SD_CHIPSELECT))
    {
      DEBUG_PRINTLNSTR("Card failed, or not present");
      // don't do anything more:
      return false;
    }
    #endif
  }
  else if (HW == HW_PHOTON)         // using photon
  {
    // #toimplement
  }
  return true;
}

/*******************************************************************************************/
/********************************L O O P***************************************************/
/*******************************************************************************************/

/*
LOOP
1) Check for Received Data pakets

2)  No message arrived. In this case the controller can check the schedule whether pumps
have to be activated and it has to check whether there have been IOT requests.
2.1) Either Test cases are processed
T1)TEST_PUMP: 1
It is a test implementation which enables a pump all 30000 times
the loop gets called. This is not very feasible but fine for testing.
T2)TEST_PUMP 2
In this mode the controller waits for N datasets of all sensornodes currently in the nodelist.(N can be set in Blumentopf.h)
This means the number of sensor nodes in the nodelist * N * INTERVAL /10 is the number of seconds between the end of one watering period and the begin of the next one.
If other nodes register in the meantime, they get ignored by this algotihm.
2.2) Or the IOT interaction will be performed here

2.3)Then

END LOOP
*/
void loop(void)
{

  //DEBUG_PRINT(":");
  //  DEBUG_PRINTLN(myNodeList.mnLastAddedSensorNode);

  #if (DEBUG_==1)
  #if(DEBUG_TIMING_LOOP>1)
  duration_loop=micros();
  #endif
  #if(DEBUG_INFO>0)
  if((millis()-time_)>20000)
  {
    #if(DEBUG_RF24>0)

    DEBUG_PRINTLNSTR("<<<<<<<<<<<<<<<<<<<<<<<<>>>>>>>>>>>>>>>>>>>>>>>");
    radio.printDetails();

    DEBUG_PRINTLNSTR("RF24-Settings:");
    DEBUG_PRINTSTR("\tRADIO_CHANNEL: ");DEBUG_PRINTLN(RADIO_CHANNEL);
    DEBUG_PRINTSTR("\tRADIO_DELAY: ");DEBUG_PRINTLN(RADIO_DELAY);
    DEBUG_PRINTSTR("\tRADIO_RETRIES: ");DEBUG_PRINTLN(RADIO_RETRIES);
    DEBUG_PRINTSTR("\tRADIO_SPEED: ");DEBUG_PRINTLN(RADIO_SPEED);
    DEBUG_PRINTSTR("\tRADIO_CRC: ");DEBUG_PRINTLN(RADIO_CRC);
    DEBUG_PRINTSTR("\tRADIO_PA_LEVEL: ");DEBUG_PRINTLN(RADIO_PA_LEVEL);
    DEBUG_PRINTLNSTR("<<<<<<<<<<<<<<<<<<<<<<<<>>>>>>>>>>>>>>>>>>>>>>>");
    #endif
    DEBUG_PRINTSTR("\n\tSize of myData: ");DEBUG_PRINTLN(sizeof(myData));
    DEBUG_PRINTSTR("\n\tSize of myResponse: ");DEBUG_PRINTLN(sizeof(myResponse));
    #if(DEBUG_TIMING_LOOP==1)
    DEBUG_PRINTSTR("[CONTROLLER][TIMING LOOP]Maximal loop time:");
    DEBUG_PRINT_D(duration_max, DEC);
    DEBUG_PRINTLNSTR(" microseconds.");
    #endif
  }//if((millis()-time_)>20000)
  #endif//#if(DEBUG_INFO>0)
  time_=millis();
  #endif//#if (DEBUG_==1)

  //uint8_t nPipenum;

  #if (TEST_PUMP == 0) //Bernhard@: LÖSCHEN ????
  uint8_t nICA;   // Interactive Command Answer
  uint8_t nSCA;   // Scheduled Command Answer
  uint16_t nDuration;
  uint16_t nID;
  #endif
  bResponseNeeded = true;    // not always a message needs to be sent
  uint8_t ret;


  //struct interactiveCommand myInteractiveCommand;
  myResponse.state = 0;
  myResponse.interval = INTERVAL;

  //DEBUG_PRINTSTR("Time before taking RTC:");DEBUG_PRINTLN(millis());
  //  myResponse.ControllerTime = getCurrentTime(); //maybe it is not clever to request time from RTC in EVERY loop
  //DEBUG_PRINTSTR("Time after taking RTC:");DEBUG_PRINTLN(millis());
  //DEBUG_PRINTSTR("[MEMORY]:Between Heap and Stack still "); DEBUG_PRINT(String(freeRam(), DEC));
  //DEBUG_PRINTLNSTR(" bytes available.");

  /**********************************************************************************************************************/
  /*
  *  1) CHECK FOR INCOMING MESSAGES
  *
  */
  //if (radio.available(&nPipenum) == true)    // 19.1.2017     checks whether data is available and passes back the pipe ID
  if (radio.available())
  {
    #if (DEBUG_INFO>0)
    #if(DEBUG_RF24>0)
    DEBUG_PRINTSTR("[CONTROLLER]RF24::Payloadsize: ");
    DEBUG_PRINT(radio.getPayloadSize());
    #endif
    DEBUG_PRINTLNSTR(".");
    DEBUG_PRINTSTR("[TIME] : ");
    displayTimeFromUNIX(getCurrentTime());
    #endif

    while (radio.available()) {

      radio.read(&myData, sizeof(myData));
    }

    // output message details only if required
    #if (DEBUG_MESSAGE_HEADER > 0)

    DEBUG_PRINTSTR("[CONTROLLER][RECEIVED]State: ");
    DEBUG_PRINTDIG(myData.state, BIN);
    DEBUG_PRINTSTR(" from ID: ");
    DEBUG_PRINT(myData.ID);
    DEBUG_PRINTSTR(" PACKETINFO BITS: ");
    DEBUG_PRINTDIG(myData.packetInfo,BIN);
    DEBUG_PRINTLNSTR("  . ");
    #if(DEBUG_MESSAGE_HEADER_2 > 0)

    DEBUG_PRINTSTR("PumpTime: ");
    DEBUG_PRINTLN(myData.pumpTime);
    DEBUG_PRINTSTR("Interval: ");
    DEBUG_PRINTLN(myData.interval);
    DEBUG_PRINTSTR("temperature: ");
    DEBUG_PRINTLN(myData.temperature);
    DEBUG_PRINTSTR("humidity: ");
    DEBUG_PRINTLN(myData.humidity);
    DEBUG_PRINTSTR("moisture: ");
    DEBUG_PRINTLN(myData.moisture);
    DEBUG_PRINTSTR("moisture2: ");
    DEBUG_PRINTLN(myData.moisture2);
    DEBUG_PRINTSTR("brightness: ");
    DEBUG_PRINTLN(myData.brightness);
    DEBUG_PRINTSTR("voltage: ");
    DEBUG_PRINTLN(myData.voltage);
    DEBUG_PRINTSTR("VCC: ");
    DEBUG_PRINTLN(myData.VCC);
    DEBUG_PRINTSTR("realTime: ");
    DEBUG_PRINTLN(myData.Time);
    #endif
    #endif

    //      myResponse.ControllerTime = 1481803260;
    //    getUNIXtime(&myResponse.ControllerTime);    // gets current timestamp

    // log the data to the SD card:
    logData();

    if ((myData.state & (1 << MSG_TYPE_BIT)) == false) // this is a registration request. Send ack-message
    {
      DEBUG_PRINTSTR_D("[CONTROLLER] Registration request", DEBUG_MESSAGE);

      handleRegistration();                 // answer the registration request. There is no difference between sensor nodes and motor nodes.
      setDATA_RegistrationPacket(&myResponse);//Helmut@: for Logging

    }
    else                                    // This is a data message
    {
      setDATA_NO_RegistrationPacket(&myResponse);//Helmut@: for Logging


      if ((myData.state & (1 << NODE_TYPE)) == false) // it is a sensor node
      {
        myResponse.Time = getCurrentTime();
        DEBUG_PRINTLNSTR_D("[CONTROLLER] SENSOR MESSAGE", DEBUG_MESSAGE);

        handleDataMessage();
        setDATA_SensorPacket(&myResponse);//Helmut@: for Logging
      }
      else                                  // it is a motor node message
      {
        //current Time stored in Moisture1 and Moisture2
        setCombinedData(getCurrentTime(),myResponse.moisture2, myResponse.moisture);
        #if(DEBUG_MESSAGE>0)
        DEBUG_PRINTSTR("[CONTROLLER] MOTOR MESSAGE:ID:");
        DEBUG_PRINT(myData.ID);
        DEBUG_PRINTSTR(", Data 1:");
        DEBUG_PRINT(myData.Time);
        DEBUG_PRINTSTR(", Data 2:");
        DEBUG_PRINT(myData.Time_2);
        #endif
        handleMotorMessage();
        setDATA_PumpPacket(&myResponse);//Helmut@: for Logging

        //        bResponseNeeded = false;
      }
    }
    //in every loop bResponseNeeded is redefined to true
    if (bResponseNeeded == true)          // If it is necessary to send an answer, send it.
    {

      //to make state changes and to turn on receiver mode, otherwise the message is lost

      //DEBUG_PRINTLN(myResponse.ControllerTime);

      // Send back response, controller real time and the next sleep interval:
      #if(DEBUG_MESSAGE>0)
      DEBUG_PRINTSTR("[CONTROLLER][SENDING RESPONSE] - interval: ");
      DEBUG_PRINT(myResponse.interval);
      DEBUG_PRINTSTR(", ID:");
      DEBUG_PRINT(myResponse.ID);
      DEBUG_PRINTSTR(", STATUS-BYTE:");
      DEBUG_PRINTLN(String(myResponse.state, BIN));
      //DEBUG_PRINTSTR(", dummy8:");
      //DEBUG_PRINTLN(String(getData_PumpState(&myResponse), DEC));
      DEBUG_PRINTSTR(", PACKET-INFO:");
      DEBUG_PRINTLN(String(myResponse.packetInfo, BIN));
      #endif

      delay(WAIT_SEND_INTERVAL);//ther is some time to, to ensure that node is prepared to receive messages     // 20170312 - Berhnard: Can we find another way for this as this solution slows down the communication and is suspected to leading to timeouts.
      #if (DEBUG_TIMING_LOOP>0)
      duration_sending=micros();
      #endif
      radio.stopListening();
      while(write_cnt > 0) //handleDataMessage and handleMotorMessage could manipulate write_cnt
      {
        radio.write(&myResponse, sizeof(myResponse));
        write_cnt--;
      }
      radio.startListening();
      #if (DEBUG_TIMING_LOOP>0)
      DEBUG_PRINTSTR("[TIMING][to ID: ");
      DEBUG_PRINT(myResponse.ID);
      DEBUG_PRINTSTR(" ][Duration of Send Operation.]: ");
      DEBUG_PRINT(micros() - duration_sending);
      DEBUG_PRINTLNSTR(" microseconds.");
      #endif
    }else{
    DEBUG_PRINTSTR_D("\tResponse sending is skipped: ", DEBUG_MESSAGE);

    }
    DEBUG_PRINTLNSTR_D("[CONTROLLER] Listening now...", DEBUG_MESSAGE);

    write_cnt=1;//reset
  }//  if (radio.available())

  else  // no message arrived. In this case the controller can check the schedule whether pumps have to be activated and it has to check whether there have been IOT requests.
  /*
  *  2) NO MESSAGE ARRIVED. CHECK PUMP SCHEDULE
  * */
  {

    /*    2.1)
    * TEST_PUMP: 1
    * It is a test implementation which enables a pump all 30000 times the loop gets called. This is not very feasible but fine for testing.
    *
    * TEST_PUMP: 2
    * It is a pump scheduling implementation which can be considered as final, if there are no other requirement requests about the pump scheduling.
    * In this mode the controller waits for N datasets of all sensornodes currently in the nodelist. (N can be set in Blumentopf.h)
    * This means the number of sensor nodes in the nodelist * N * INTERVAL /10 is the number of seconds between the end of one watering period and the begin of the next one.
    * If other nodes register in the meantime, they get ignored by this algotihm.
    *
    *

    */
    #if (TEST_PUMP == 1)
    /* this is only for testing!! */
    // DEBUG_PRINTLN(nTestWatering);

    if (myNodeList.mnNodeCount > 0) {
      if(i_ >= myNodeList.mnNodeCount)
      {
        i_= 0;
      }
      nTestWatering++;
    }

    if ((nTestWatering % 1000) == 0 )
    {
      if(PumpList.size()==0)
      {
        if (myNodeList.getNodeType(myNodeList.myNodes[i_].ID) == 1)//Pump Node
        {
          DEBUG_PRINTSTR_D("\t[CONTROLLER][TEST] Node id: ", DEBUG_MESSAGE);
          DEBUG_PRINTLN_D(myNodeList.myNodes[i_].ID, DEBUG_MESSAGE);

          if (myNodeList.isActive(myNodeList.myNodes[i_].ID) == 0)//check if the first node (index=0)in the list is active
          {
            if(i_2==0){
              ret = doWateringTasks(myNodeList.myNodes[i_].ID, 0,10000, 0); //here a new order to a pump Node has to be planned
              if(ret==0)
                i_2++;
            }else if(i_2==1){
              ret = doWateringTasks(myNodeList.myNodes[i_].ID, 10000,0, 0);
              if(ret==0)
                i_2++;
            }else if(i_2==2){
              ret = doWateringTasks(myNodeList.myNodes[i_].ID, 10000,5000, 0);
              if(ret==0)
                i_2++;
            }else if(i_2>=3){
              ret = doWateringTasks(myNodeList.myNodes[i_].ID, 5000,10000, 0);
              if(ret==0)
                i_2=0;
            }
            #if(DEBUG_MESSAGE>0)
            if (ret > 0) {

              DEBUG_PRINTLNSTR("\t[CONTROLLER]ERROR: DOWATERING FAILED! ");
              DEBUG_PRINTSTR("\t[CONTROLLER]");
              DEBUG_PRINTLN(handle_ErrorMessages(ret));
              /*Marko@: Some more Error handling necessary?*/
            }
            #endif
          }
          #if(DEBUG_MESSAGE>0)
          else
          DEBUG_PRINTLNSTR("\t[CONTROLLER][TEST] WARNING: Node already in use.");
          #endif
        }
        i_++;
      }

    }
    /* Testing end */
    #elif (TEST_PUMP == 2)
    /* second test .. or real mode..we will see*/
    time_t myCurrentTime;
    static bool bProcessPumps = false;
    uint16_t SensorNode_Pump1;
    uint16_t SensorNode_Pump2;
    bool sens1_mo1=false,sens1_mo2=false,sens2_mo1=false,sens2_mo2=false;

    nTestWatering++;

    if (myNodeList.mnPumpSlotEnable == true)
    {

      //      DEBUG_PRINTSTR("[TIME] : ");
      myCurrentTime = getCurrentTime();
      //      displayTimeFromUNIX(myCurrentTime, 1);

      if (bProcessPumps == false)
      {

        if (myNodeList.mnPumpSlot <= myCurrentTime)      // The sensorNode-slots are over. Now it's time to go through the pumps and activate them if needed.
        {

          #if (DEBUG_LIST_PUMP_SCHEDULING>0)
          time_t nextpumpSlot=myCurrentTime;
          time_t nextpumpSlot2= myNodeList.myNodes[myNodeList.getLastScheduledSensorNode()].nextSlot
                                + myNodeList.getNumberOfNodesByType(SENSORNODE) * (INTERVAL /10) * myNodeList.mnCycleCount;

          DEBUG_PRINTLNSTR("\r\n[TEST_PUMP=2]\tAll data arrived. Activating the pumps...");
          DEBUG_PRINTLNSTR("-----------------------------------------------------------");
          DEBUG_PRINTLNSTR("ONLINE PUMPS:");
          for(int i=0;i<myNodeList.mnNodeCount;i++)
          {
            if(myNodeList.getNodeType(myNodeList.myNodes[i].ID)==1)
            {
              DEBUG_PRINTSTR("PumpNode ID ");
              DEBUG_PRINT(myNodeList.myNodes[i].ID);
              DEBUG_PRINT(" - ");
              displayTimeFromUNIX(nextpumpSlot, 1);
              DEBUG_PRINT(" ");
              DEBUG_PRINT(" - ");
              displayTimeFromUNIX(nextpumpSlot2, 1);
              DEBUG_PRINTLN(" ");
              nextpumpSlot += INTERVAL / 10;
              nextpumpSlot2 += INTERVAL / 10;
            }
          }
            DEBUG_PRINTLNSTR("-----------------------------------------------------------");
          #endif
          bProcessPumps = true;
          myNodeList.mnActivePump = 0;


        }
        #if(DEBUG_MESSAGE>0)
        else
        {
          DEBUG_PRINTLNSTR_T("\t[TEST_PUMP=2]Waiting until the pump timeslot starts..", DEBUG_CYCLE, nTestWatering);

        }
        #endif

      }

      if (bProcessPumps == true)    // The pumps have to be processed?
      {
        //Bernhard@ only checkl PumpList.size()==0 and else is under Debug wrapping, can be optionally compiled
        if (PumpList.size() == 0)    // are there still active pumps?
        {
          DEBUG_PRINTLNSTR_D("\t\t No currently active pump.. Next pump can be started.", DEBUG_MESSAGE);
          // Now the pumps have to be processed, one after the other.
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

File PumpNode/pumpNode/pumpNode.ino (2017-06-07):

/*
   Project: NESE_Blumentopf
   File:    pumpNode.ino
   Authors: Bernhard Fritz  (0828317@student.tuwien.ac.at)
            Marko Stanisic  (0325230@student.tuwien.ac.at)
            Helmut Bergmann (0325535@student.tuwien.ac.at)
   The copyright for the software is by the mentioned authors.

   This program uses a set of sensors to gather information about it's surrounding.
   It registers to a controller and periodically sends the data to the controller.
   During the measurements the setup goes into a low power mode.

*/


/**************PUMP NODE SETTINGS****************************/
//#include <SPI.h>
#include "printf.h"
#include "Blumentopf.h"

//#include "nRF24L01.h"
//#include "RF24.h"
#include <EEPROM.h>

//function to initiate radio device with radio(CE pin,CS pin)
RF24 radio(CE_PIN, CS_PIN);




/****************** User Config ***************************/
bool bounce = false;

uint32_t started_waiting_at = 0, previousTime = 0, dif = 0, criticalTime = 0, waitonPump = 0, OnOff_1 = 0, OnOff_2 = 0, answer_1 = 0, answer_2 = 0;
uint32_t pump_worktime_1 = 0;
uint32_t pump_worktime_2 = 0;
#if (DEBUG_TIMING_LOOP>0)
uint32_t timing_ = 0;
#endif
const uint8_t pumpPin_1 = PUMP1_PIN;//3
const uint8_t pumpPin_2 = PUMP2_PIN;//2
const uint8_t buttonPin = BUTTON_PIN;//4
uint8_t write_cnt = RADIO_RESEND_NUMB;
int status; //normal states are positive numbers , erro states are negative
int buttonstate = 0;
bool pumpOn_1 = false;
bool pumpOn_2 = false;
//byte addresses[][6] = {"Pump", "Contr"};
//const uint64_t pipes[3] = {0xF0F0F0F0E1LL, 0xF0F0F0F0D2LL, 0xE8E8F0F0E1LL};
const uint64_t pipes[2] = {0xF0F0F0F0E1LL, 0xF0F0F0F0D2LL};


/******************************/
struct Data myData;
struct Data myResponse;

#if (DEBUG_RF24 == 1)
uint32_t time_;
#endif



/************************************************************************************************/
/*********************************S E T U P*******************************************************/
/***********************************************************************************************/
void setup() {


  DEBUG_SERIAL_INIT_WAIT;
  printf_begin();
  pinMode(pumpPin_1, OUTPUT);
  pinMode(pumpPin_2, OUTPUT);
  pinMode(buttonPin, INPUT);
  randomSeed(analogRead(0));//initialize Random generator

  //killID();
  //radio.begin();
  radio.begin(RADIO_AUTO_ACK, RADIO_DELAY, RADIO_RETRIES, RADIO_SPEED, RADIO_CRC, RADIO_CHANNEL, RADIO_PA_LEVEL);
  //radio.setPALevel(RF24_PA_LOW);
  //radio.setChannel(RADIO_CHANNEL);

  radio.openWritingPipe(pipes[1]);        // Both radios listen on the same pipes by default, but opposite addresses
  radio.openReadingPipe(1, pipes[0]);     // Open a reading pipe on address 0, pipe 1

  radio.startListening();                       // Start listening

#if (DEBUG_==1)
#if (DEBUG_RF24==1)
  radio.printDetails();
#endif
#if (DEBUG_INFO == 1)

  DEBUG_PRINTSTR("\n\tSize of myData: "); DEBUG_PRINTLN(sizeof(myData));
  DEBUG_PRINTSTR("\n\tSize of myResponse: "); DEBUG_PRINTLN(sizeof(myResponse));
#endif
#endif


  myData.humidity = 0.0f;
  myData.moisture = 0;
  myData.moisture2 = 0;
  myData.brightness = 0;
  myData.voltage = 0;
  myData.VCC = 0;
  myData.Time = 0;
  myData.Time_2 = 0;
  myData.packetInfo = 0;

  setDATA_PumpPacket(&myData);
  setDATA_NormalDatapacket(&myData);
  setDATA_RegistrationPacket(&myData);
  //myData.dummy16 |= (1 << DATA_NODE_BIT); //packet is identified as pump packet
  //myData.dummy16 |= (1 << DATA_REGISTRATION_BIT); //packet is identified registration packet
  DEBUG_PRINTSTR("[PUMPNODE]");
  DEBUG_PRINTSTR("[MYDATA PACKETINFO before REGISTRATION]:");
  DEBUG_PRINTDIG(myData.packetInfo, BIN);
  DEBUG_PRINTLNSTR("");
  //Print debug info
  //radio.printDetails();

  //criticalTime = PUMPNODE_CRITICAL_STATE_OCCUPATION/2; //software watchdog looks for freesing states
  criticalTime = (uint32_t)(PUMPNODE_CRITICAL_STATE_OCCUPATION / 2); //software watchdog looks for freesing states
  DEBUG_PRINTSTR("[PUMPNODE]");
  DEBUG_PRINTSTR("CRITICALTIME:");
  DEBUG_PRINTLN(criticalTime);

  registration(true);

  myData.state |= (1 << NODE_TYPE);       // set node type to pump node
  myData.state |= (1 << MSG_TYPE_BIT);    // set message to data (to ensure in case it got overwritten)
  setDATA_NO_RegistrationPacket(&myData);
  //myData.dummy16 &= ~(1 << DATA_REGISTRATION_BIT);
  DEBUG_PRINTSTR("[PUMPNODE]");
  DEBUG_PRINTSTR("[MYDATA PACKETINFO]:");
  DEBUG_PRINTDIG(myData.packetInfo, BIN);
  DEBUG_PRINTLNSTR("");
}
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

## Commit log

2016-11-30 Added a battery voltage measurement example, a draft of the measurement node and a simple controller.
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2016-12-02 Added basic components of the network protocol (node registration and ID generation) The node stores its ID in EEPROM now, so every new node of the network will get an ID from the controller and keep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
    [RF_Receiver.ino, SensorNode.ino]
2016-12-02 Added basic components of the network protocol (node registration and ID generation) The node stores its ID in EEPROM now, so every new node of the network will get an ID from the controller and keep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
    [RF_Receiver.ino, SensorNode.ino]
2016-12-16 Added fritzing for SensorNode - Fabrication Version
    [PlantSensorPCB10.fzz]
2016-12-19 continued EEPROM data storage implementation. Changed battery voltage measurement to voltage divider technique. Cleaned up code bit. Added a draft of the controller diagramm.
2016-12-20 RTC Modul DS3231 getestet mit OutputPin als Stromversorgung, Externer Interrupt; Libraries DS3232RTC und LowPower hinzugefügt
2017-01-02 Finished the Battery Voltage Reading. Maybe an adjustment for the 1V1 reference can be done in future.
2017-01-05 RTC will only be accessed when power-pin is enabled. Also the TWI pins will be disconnected before standybe. So now the RTC VCC can be connected to the power-pin for improved power savings.
2017-01-09 Fritzing file for PumpNode
    [PlantPumpPCB.fzz]
2017-01-12 added PumpNode and Fritzing with Pumpnode controlled only by transistor
    [PlantPumpPCB.fzz, PlantPumpPCB01.fzz]
2017-01-12 Fritzing file for PumpNode with Relay, but still no finished, should be checked.
    [PlantPumpPCB01.fzz, PlantPumpPCB10.fzz]
2017-01-13 PumpNode Fritzing finished
    [PlantPumpPCB10.fzz]
2017-01-15 Added the node-file management to the controller draft. Updated the readme.txt and SensorNode.
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2017-01-17 Corrected some failures in Test Pump Node and Test Controller, added more Debuf information
    [turnOnOff_RFv3.ino]
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2017-01-19 Fixed bugs with the NodeList
    [Controller.ino, SensorNode.ino]
2017-01-19 Fixed bugs with node management. Implemented small node list in EEPROM
    [Controller.ino, SensorNode.ino]
2017-01-20 Safe a version of pumpnode 2.9(from version 3 with interrupts, But we will not use it anymore)
2017-01-22 1)Arduino IDE library setting should be chaged to that repository 2)Added second confirmation in the pumpnode to the controller 3) Pump Node file created
2017-01-23 Adapted Pumpnode to the Blumentopf Protocoll, no compile errors but not yet tested
    [pumpNode.ino]
2017-01-23 Fixed registration bug in pump node. Added a timeout for the controller response.
    [pumpNode.ino]
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2017-01-25 Implemented the pumpNode according the Blumentopf protocol,invented new Class PumpNode_Handler,invented the Pump node State machine in the documentation
2017-01-25 Changed hard coded baud rate to BAUD define. Fixed a return value data type bug. Fixed a bug in the response of the pumpNode.
    [Controller.ino, pumpNode.ino]
2017-01-25 Fixed some more bugs in the protocol between controller and pump node. Pumping still doesn't work correctly, but registration and the first state machine states seem fine (at least better) now.
    [Controller.ino, pumpNode.ino]
2017-01-25 handleMotorMessage implemented, handleRegistration corrected
    [Controller.ino, pumpNode.ino]
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2017-01-26 Started to implement pump scheduler, but it's still disabled because normal pump communication has to be made stable before.
2017-01-30 pumpNode seems to work now, but ther are some bugs remaining
    [Controller.ino, pumpNode.ino]
2017-01-30 1)PumpNode integrated in the Blumentopf Protocol seems to work, but I will test it more detail 2) Integrated Preprocessor abstraction of the RTC, so my RTC (DS3231 for pi) is working to on the contro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
2017-01-31 1)A lot of changes to improve stability of communication, BUT NOT YET tested 2)ControllerTime will be send
    [Controller.ino, pumpNode.ino]
2017-01-31 Forgot something in resolving Pumphandler Error State
    [Controller.ino]
2017-01-31 Inserted a log file, show how uncertain communication is and changed channel
2017-02-01 1)PumpNode really works well with the Controller 2)pumpingTime have to be passed as ms now to doWateringTasks
2017-02-02 resolved some problem with to much memory usage
    [Controller.ino, pumpNode.ino]
2017-02-02 Fixed bugs in the recent commit to make controller and sensornode compatible again. Also fixed an RTC3232 bug.
    [Controller.ino, SensorNode.ino, pumpNode.ino]
2017-02-03 Implemented sensor node scheduling. It is successfully tested with one sensor node. More tests will follow.
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2017-02-08 Fixed compile error in Controller, only sensornode not compileable,jeelib library not available
    [Controller.ino, SensorNode.ino]
2017-02-11 1) some error fixed in the registration process 2)added a button(Pin D4) to he pumpnode to initiate registration -less than 2 sec -> registration with stored ID in the eeprom -more than 2 sec -> regi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
    3)added Numbering for pumphandler(Controller) because of debug purposes
    4)added Time in DEBUG output
    [Controller.ino, pumpNode.ino]
2017-02-11 1) added some debug information regarding Test_1 Pumpnode test 2)fixed an logical problem in pumpnode 3)if communication with pumpnode fails too often, MAX_RETRIES fix the maximal retry number, then 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
    [Controller.ino, pumpNode.ino]
2017-02-16 -) changed nodelist length to 20 -) restructured and simplified the RTC settings -) restructured time display (If DS3232 uses a different format, please adjust it directly in displayTimeFromUNIX usin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
2017-03-11 fixed bug with controller-timestamp introduced with the c9301... commit ()
    [Controller.ino, SensorNode.ino]
2017-03-11 Fixed some time representation issues
    [Controller.ino, SensorNode.ino]
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2017-03-17 -) Minor adaption for DS1302 -) Pumpnode deletes its ID every time for testing purposes
2017-03-17 -) Added DEBUG flags to switch certain debug messages on/off. Otherwise the output looks messy -) Moved the output of the free ram to an own function -) Added a nodelist print function for debugging 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
2017-03-21 -) Implemented time slot based PumpNode scheduling -) Bugfix: Specified interval duration in case controller replies get lost. -) Further cleaned up debug messages and added further debug defines -) 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
    [Controller.ino, SensorNode.ino, pumpNode.ino]
2017-03-22 -) Added the fallout-mechanism description to the lab report -) Added the second moisture sensor to sensornode and controller
2017-03-30 PORT CONTROLLER FROM ARDUINO TO PARTICLE WORKS 1)added Documentation for the port in Doku/Particle 2)added a script to create symbol links in folder Controller, which is necessary for the ATom IDE(fl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
2017-04-04 1) Fixed some error in particle version of controller 2)Added A requirement text file in folder documentation to keep track of important changes/requirements if someone wants to setup Blumentopf
    [Controller.ino]
2017-04-10 Temporary Status of development: Some fixes for RF24 library and for particl RF24. Introduced Requirements for all Nodes as a Document, Some other fixes in the Blumentopf library, tried to improve so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
    [Controller.ino, SensorNode.ino, pumpNode.ino]
2017-04-12 Blumentopf works now on particle and Ardiuino - > TEST_1 succesfull a) there was a problem with the alignment discrepance of the structure myData and myResponse ,because on Sparc(Photon) the alignmen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
    [Controller.ino]
2017-04-13 Added Generator library for generating RF24 pipe adresses Library does following: -) generate a 5 Byte adress for a communication pipe,such a adress belongs to a group of maximum 5 adresses, where on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
2017-04-13 -) Generalised getNumberOfSensorNodes() to getNumberOfNodesByType() -) Fixed a scheduling bug when no pumpnode is online
    [Controller.ino, SensorNode.ino]
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2017-04-23 Started a improved Version of Controller-PumpNode interaction: Idea: Every Message from Controller or from pumpNode is retransmitted several times to ensure stability of communication, fixed some Err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
    [Controller.ino]
2017-04-25 1) Created plan for a new State machine regarding pumpNode 2)struct Response and struct sensorData is merged to one datastructure struct Data changes done in Blumentopf.h .cpp and SensorNode.ino to b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
    [Controller.ino, SensorNode.ino, pumpNode.ino]
2017-04-26 Corrected Plan for Statemachine OF the PumpNode
2017-04-26 Beginning to modify State Machine in Controller and pumpnode, and some Debug outputs added
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2017-04-27 Finished new PumpHandler Schedule on Controller.ino and PumpNode.ino, its compileable but not tested, a lot of fixes has been done: Blumentopf.cpp and Controller.ino
    [Controller.ino, pumpNode.ino]
2017-04-27 Some addtiional fixes in the Pumphandler
    [Controller.ino]
2017-04-28 1) introduced packetInfo state Byte in struct Data to have an easier monitoring about Data Packets, 2)Fixed an Alignment problem again, 3)changed struct DATA, so that interval is not used anymore for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
    [Controller.ino, pumpNode.ino]
2017-04-29 1)Fixed a very delicious Timing problem between Controller and PumpNode 2)Added a lot Debug Stuff, new defines controll their output, every Debug message ONLY INSIDE LOOP can be switched On/Off -) Ti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
    [Controller.ino, pumpNode.ino]
2017-04-30 Some modifications and some error fixes
    [Controller.ino, pumpNode.ino]
2017-05-01 PUMPHANDLER SEEMS TO WORK NOW AS IT SHOULD, Test with two pumps succesfull
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2017-05-03 -) Added delay between RTC power on and RTC init. -) Changed the HW_RTC_PIN define -) Set DEBUG_RF24 to 0 as it makes the arduino crash. -) Tested with two sensor nodes and two pumpnodes. It looks go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
    [Controller.ino, pumpNode.ino]
2017-05-03 -) Pump scheduler now supports two pumps per pumpnode. doWateringTasks() still has to be adapted for two pumps. -) Minor debug output adaptions
2017-05-07 1)not restart of PumpNode anymore, will be started in cyclic period, so thats better solution, 2)in TEST_PUMP==2 reoriented some code for better flexibility (PumpList.size()==0) 3)getLastScheduledSen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
    [Controller.ino]
2017-05-07 FINISHED CHANGES for Interaction between SensorNodes and PumpNodes, but have to be tested -) introduced new debug output depending on a running variable to get delayed outputs -) deleted for loop, if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
2017-05-07 SUCCESFULLY TESTED WITH 1 SENSORNODE AND 1 PUMPNODE -) added additional conditions to activate a pump problem: lightsensor and voltage values from sensornode where not correct, code has to be reviewed
    [Controller.ino]
2017-05-08 VOLTAGE DIVIDER CORRECTED, -) Failure before ~10% , corrected has failure of ~1% V_ADC_MAX should be 1,1V because if analog Interbal Referenz , but V_max was set on 6,0V, changed it to 6,6 V, which g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
2017-05-11 Worked on Particle CLoud implementation: 1)A particle variable is shown online -)every particle Variable is String with all combined values, Not for beatuful output only raw values -)the number of tr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
    ToDo: Online Mapping function : -which SensorNodes to Track(max 20 Nodes), PumpNode -> SensorNode
    git commit -m
2017-05-11 Worked on Particle CLoud implementation: 1)A particle variable is shown online -)every particle Variable is String with all combined values, Not for beatuful output only raw values -)the number of tr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
2017-05-11 Fixed a problem in class HomeWatering
    [Controller.ino]
2017-05-13 CHANGE PUMPNODE AND CONTROLLER Now every PumpNode has two pumps, PumpNode and Controller are changed in that way
2017-05-14 -) Fixed some Errors -) 2 pumps in series works now -) 2 pumps in parallel seems to work, but some cases are not clear, more testing necessary Tested with Test_Pump == 1
    [Controller.ino, pumpNode.ino]
2017-05-16 -) Fixed some errors -) 2 Pump functionality tested on a PumpNode with TEST_PUMP==1 successfully -) pumping in series or parallel or a pumpnodes works, can be swiched -) some error occured WITH THE P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
    [Controller.ino]
2017-05-17 PumpHandling(Two pumps on a PumpNode) in Corporation with SensorNodes finished, should be still tested 1)Watering Infiormation is stored in nodeData of a PumpNode, was unused 2)SensorID1, SensorID2 c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
2017-05-21 1)added CLOUD function for mapping Pump to Sensor 2)added a DHT library for use either for DHT11 or DHT22 Tried old DHT library Code with DHT22 but it didnt work, so I use the Adafruit Lib instead
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2017-05-22 Public.subscribe worksgit add .git add .git add .git add .! and Some fixes
    [Controller.ino]
2017-05-24 HOMEWATERING CLOUD FUNCTIONS MODIFIED / ADDED 1)Publishing SensorData modified, because maximal String length is very limited 2)Cloud Variables advanced with detailed information about SensorNodes(mu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
    [pumpNode.ino]
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2017-05-30 -)DEBUG OUTPUTS - SHOW PUMPNODES LIST -)some fixes
    [Controller.ino]
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2017-05-31 SOME FIXES TO CLOUD MAPPING FUNCTION -)some fixes in findNode() function -)every pumpNode which registrates is initally not dedicated not to a sensor -)TEST WITH 2 PUMPS AND 1 SENSOR WAS SUCCESSFULL 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
    [Controller.ino, SensorNode.ino]
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2017-06-02 Randomized the pause duration after failed registrations to avoid collisions.
    [SensorNode.ino, pumpNode.ino]
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2017-06-06 Fixed a bug that after wrong EEPROM data the ID is compromised. (Didn't fix EEPROM Bug though)
    [SensorNode.ino]
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2017-06-06 removed button stuff..version doesn't work.
    [SensorNode.ino]
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
